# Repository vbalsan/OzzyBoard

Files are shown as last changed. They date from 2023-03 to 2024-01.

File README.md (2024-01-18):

# OzzyBoard
Allwinner V3s prototype SBC

Features : 
- Allwinner V3s SoC 1.2Ghz cortex-A with 64MB ram
- STM32F0, accessible through i2c and UART
- Interface for 0.91" OLED screen
- CH340N for serial through USB
- 40 pin screen interface for Adafruit 7"
- Audio with 3.5mm jack
- 8GB eMMC

Update 15/01/2024
Received the Rev B, changes are in the readme of its folder, main improvements are :
- Ethernet port right side
- Changed power supply of Serial to USB chip for the board own power, no accidental pull down now
- Heartbeat led added
- Added +5V port
- Added buttons
- EEPROM
- More leds...

Update 31/07/2023
- I realized that the LED I added for RX on UART0 is pulling the signal down if no USB with power is connected, resulting in getting stuck in uboot prompt at start, I will desolder it.
- forgot pull-up for I2C, so PMIC was impossible to talk to, fixed with internal pull-up in device tree.
- Tested LCD backlight, it works
- Tested LED on the back side with PWM, works fine too, I may use that with a kernel module to signal statuses. (uploaded a pic for it)
- Need to try transfering Uboot and Linux on eMMC

Update 05/05/2023
- Ethernet port LNK led is not working, mixed up connections, the eth connector has pin 9 as anode and 10 cathode, but on Kicad this was inverted.
- Board booting fine with kernel 6.1
- Made a custom device tree but with sunxi dtsi
- eMMC can be partitioned and formatted, perf test show +/- 40MB/s write or read
- Ethernet works, need to configure /etc/network/interfaces and add it to rootfs overlay though

Update 23/04/2023 :
- Ethernet port is inverted... 3D model on kicad was not accurate, lesson learned. Will replace with vertical models
- Green external led for LNK is too bright, Vf is equal to 2.7V for a forward current of 1mA and not typical 3V, so current in the end is more like 2mA
- Didn't test screen, need to update BSP with new device tree
- Power consumption is around 80mA, not bad

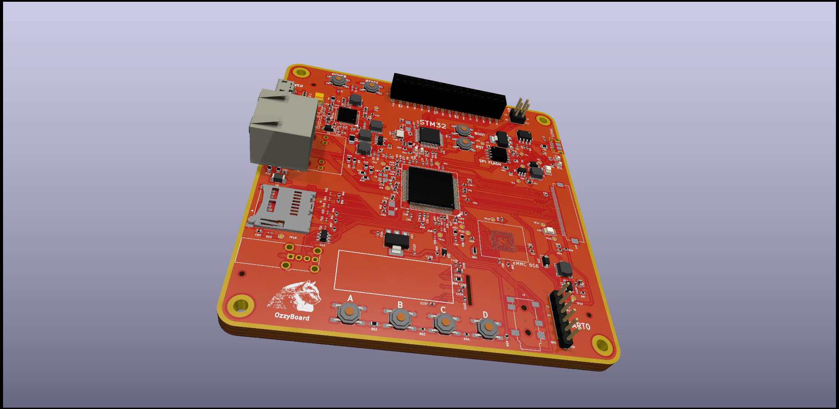
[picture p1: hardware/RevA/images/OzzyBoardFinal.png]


Board received : 
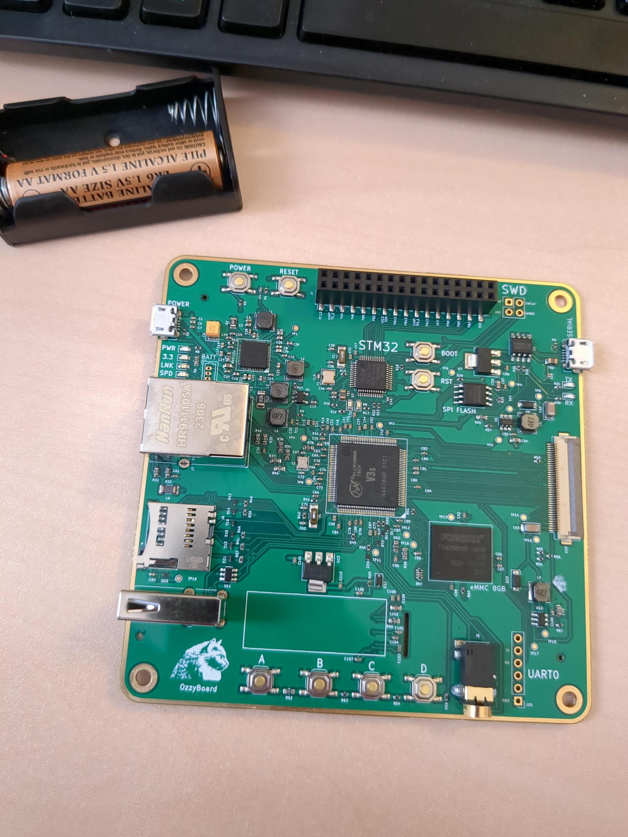
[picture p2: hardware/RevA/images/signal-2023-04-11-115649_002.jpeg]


Board with vital LEDs :
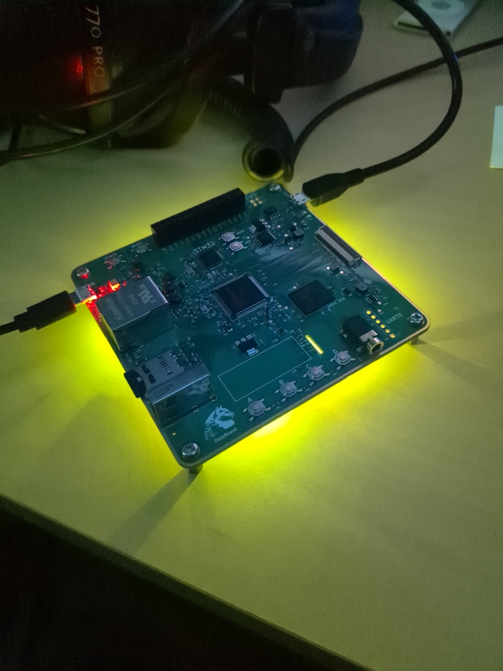
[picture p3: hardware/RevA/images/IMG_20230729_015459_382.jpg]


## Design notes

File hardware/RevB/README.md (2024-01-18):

# OzzyBoard
Allwinner V3s prototype SBC RevB

- Changed the Ethernet port , also this time it is right side
- Changed power supply of Serial to USB chip for the board own power, no accidental pull down now
- USB ports are more on board
- Heartbeat led added on PF6
- battery pins are bigger, JST model
- Added port for +5V
- UART serial port is now near serial usb
- Added func button
- Pull-up for i2c
- Added leds for CPU and Memory activity, through shift register

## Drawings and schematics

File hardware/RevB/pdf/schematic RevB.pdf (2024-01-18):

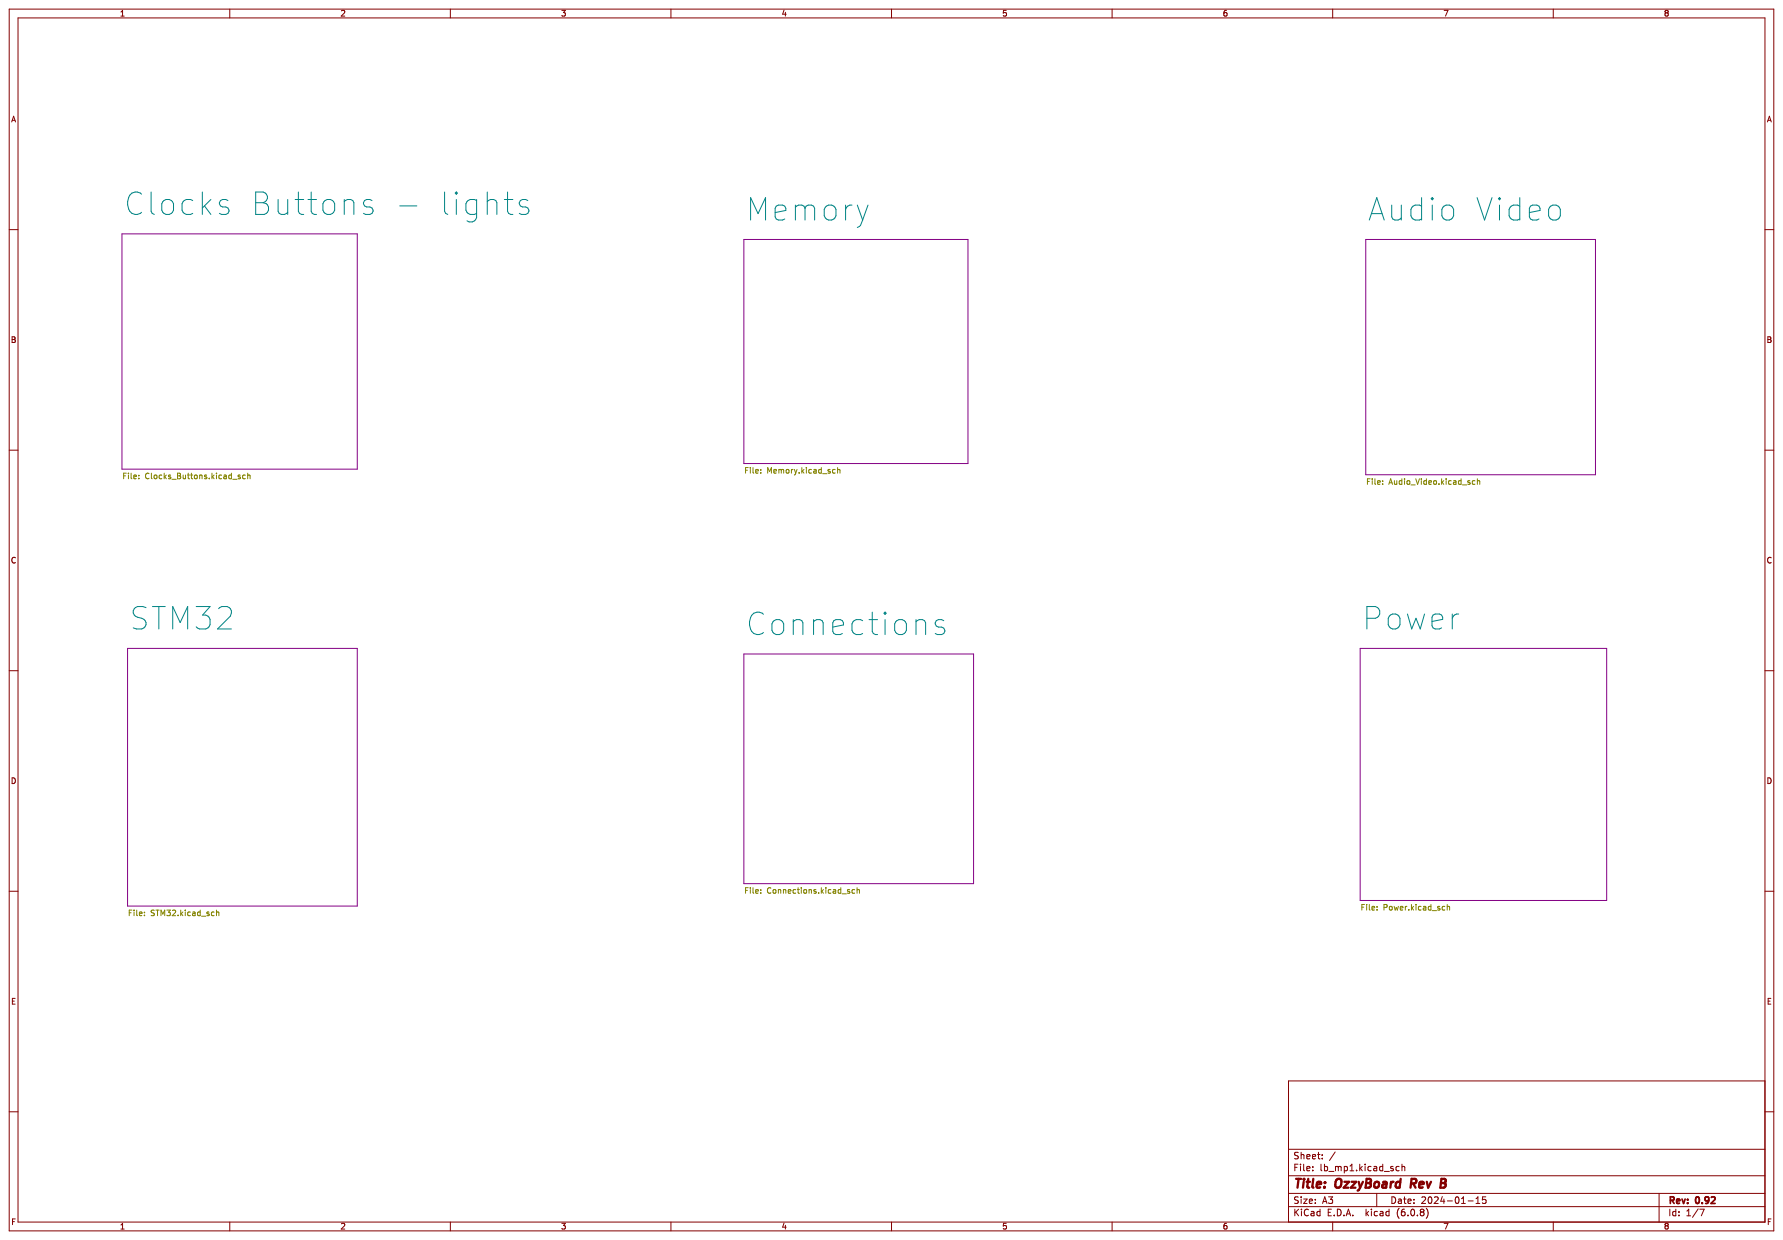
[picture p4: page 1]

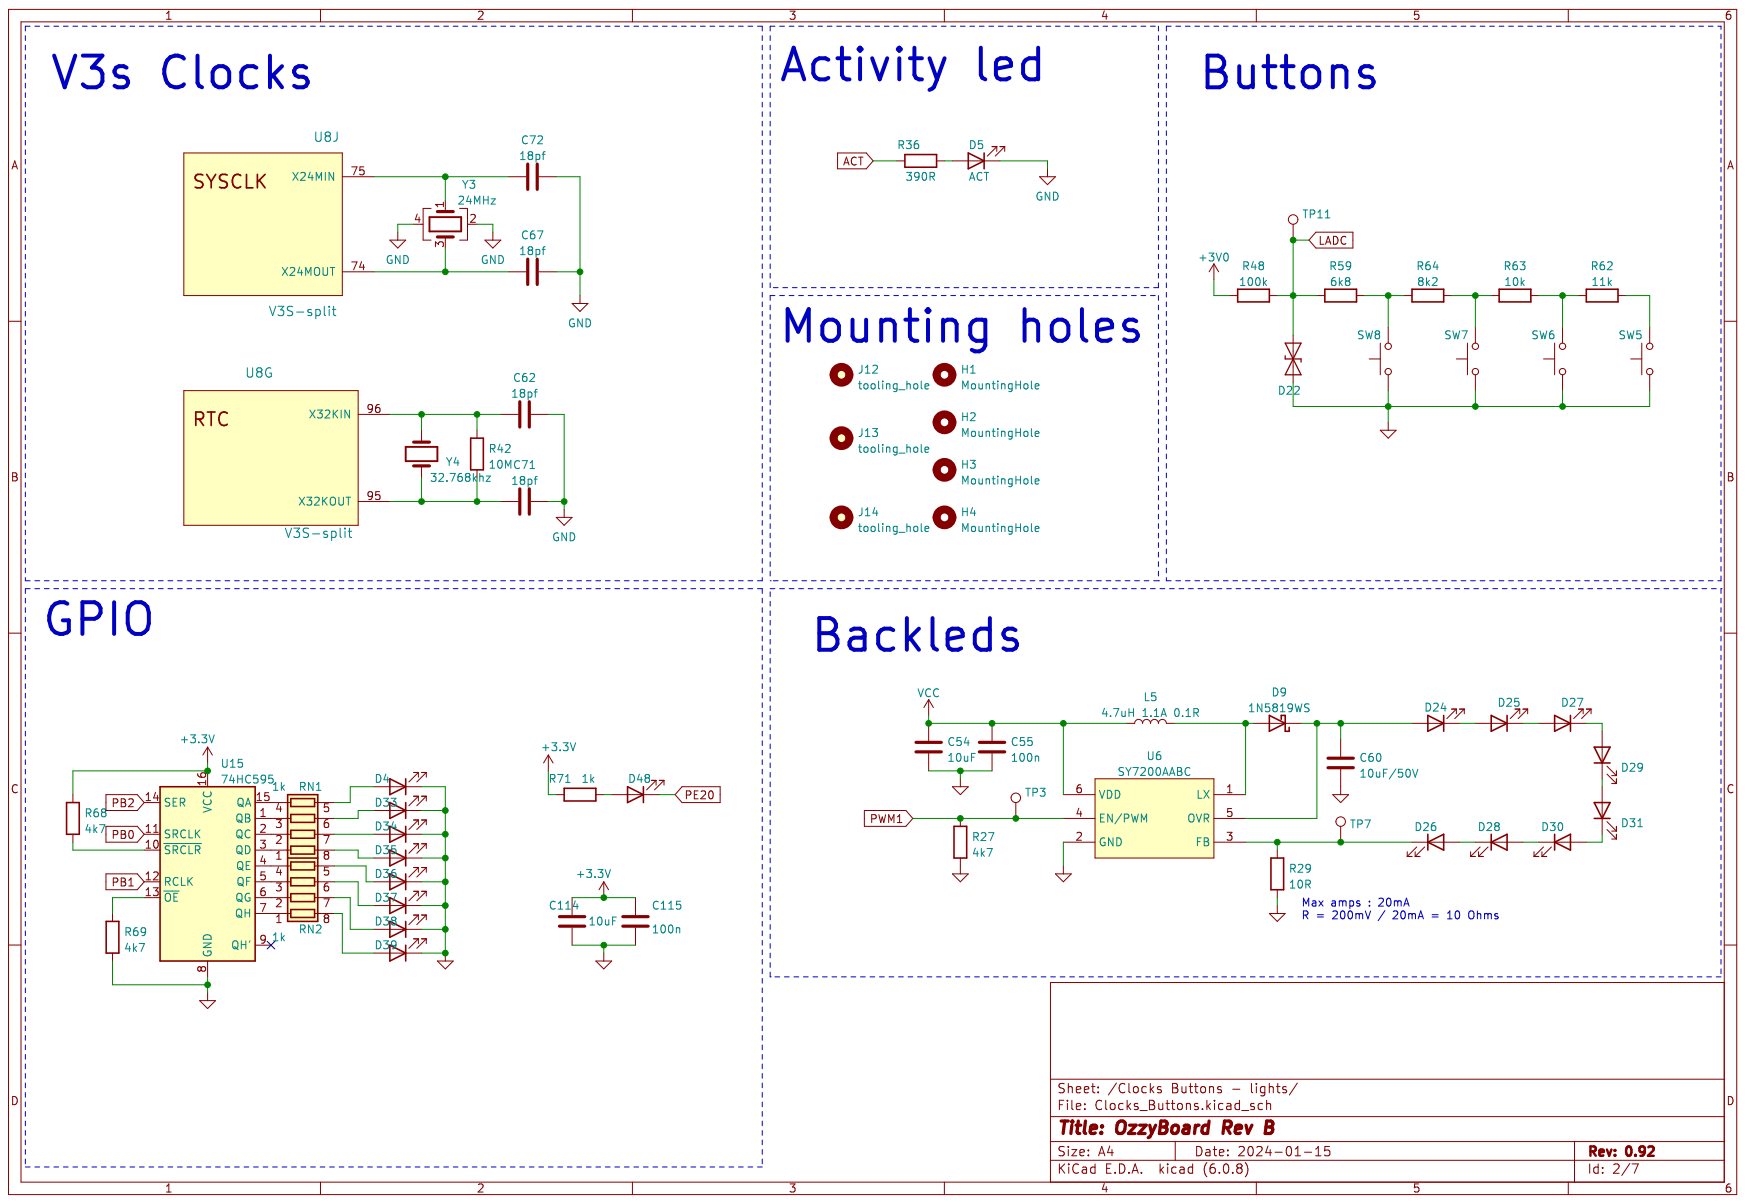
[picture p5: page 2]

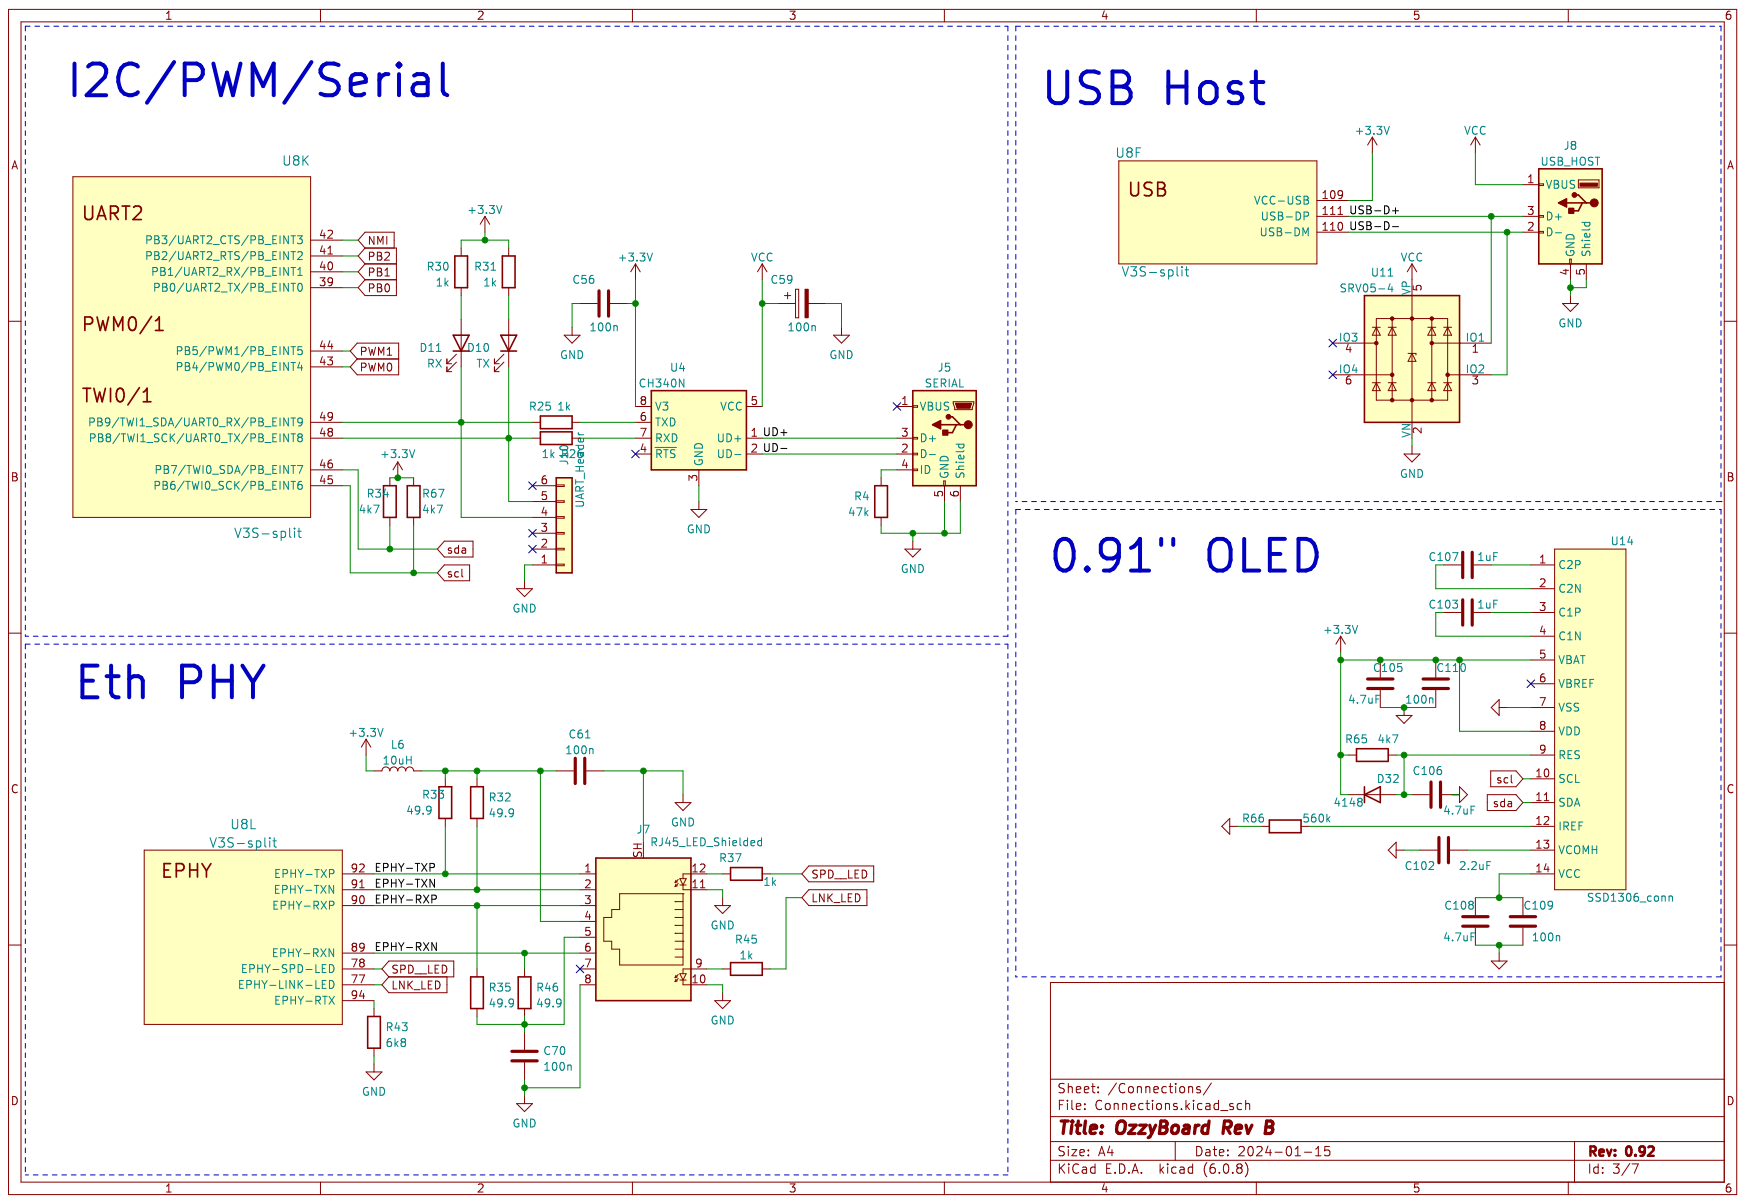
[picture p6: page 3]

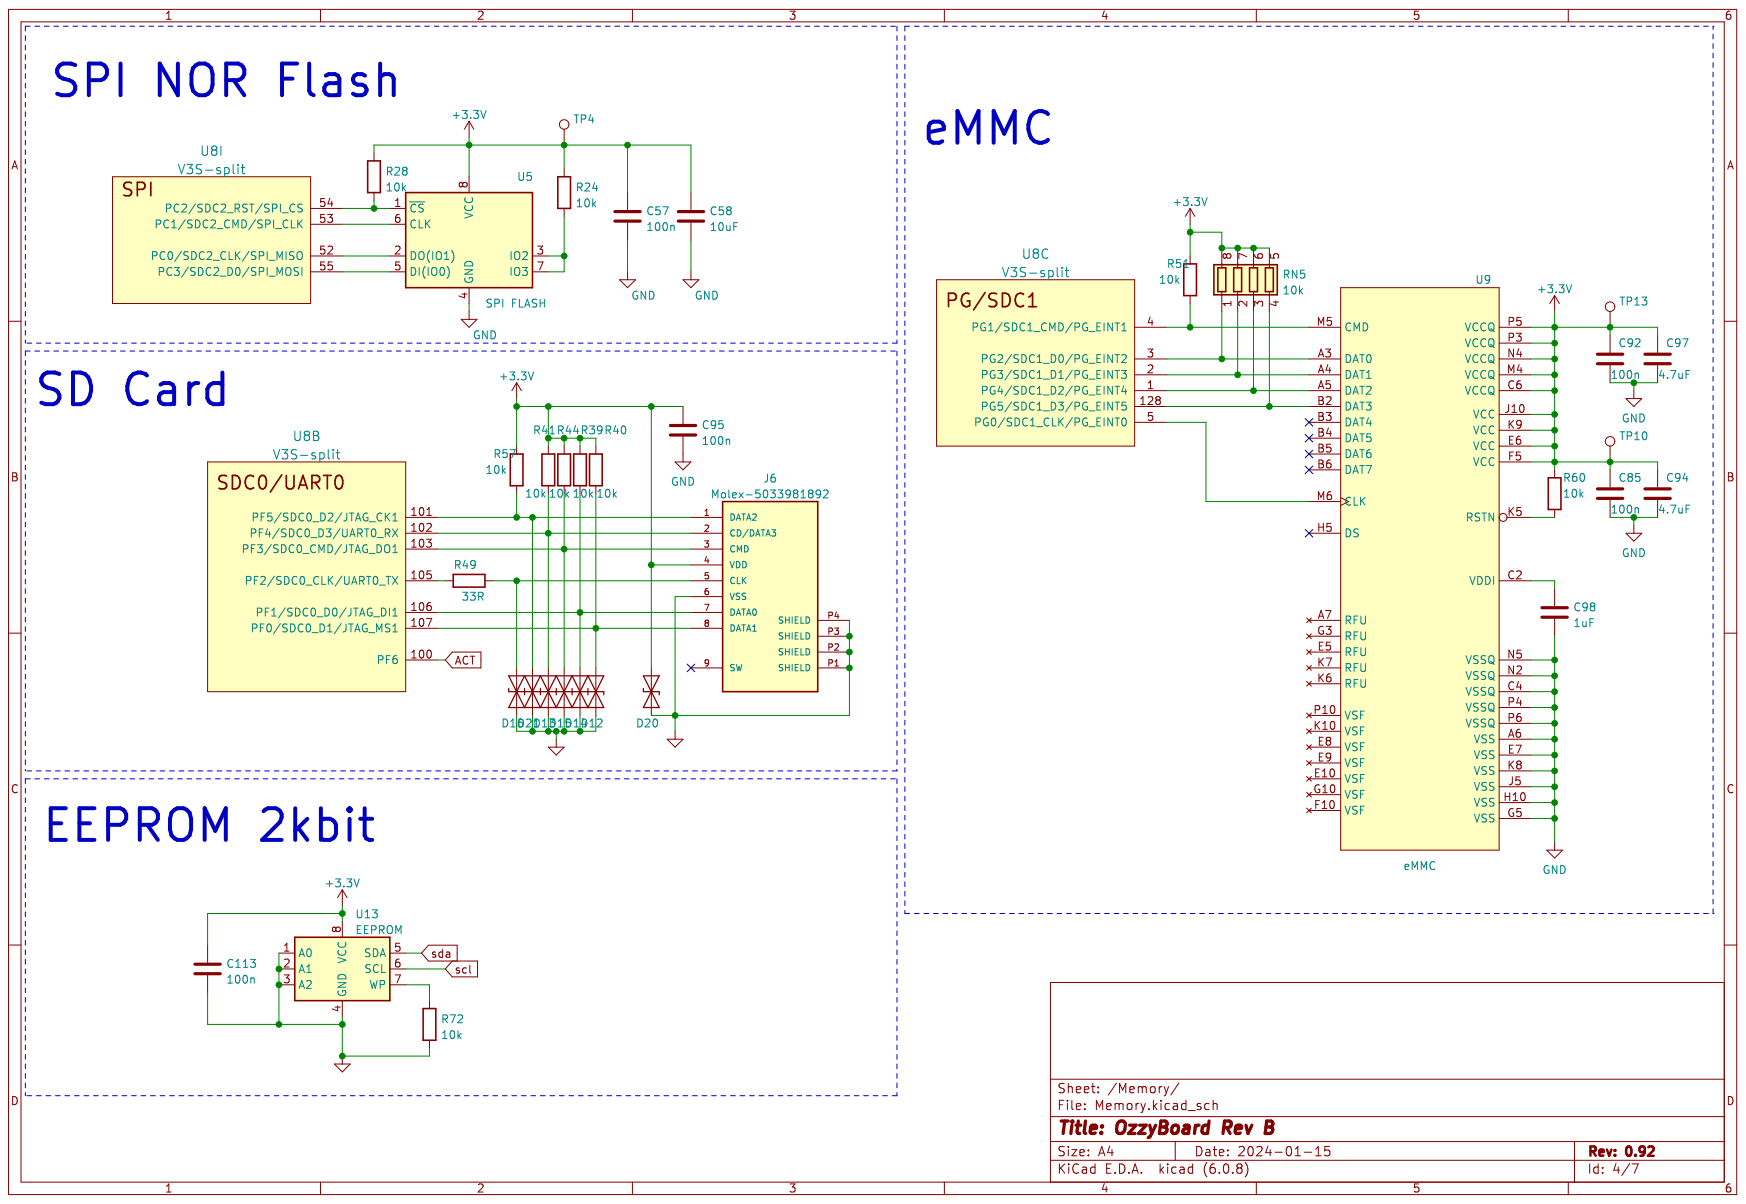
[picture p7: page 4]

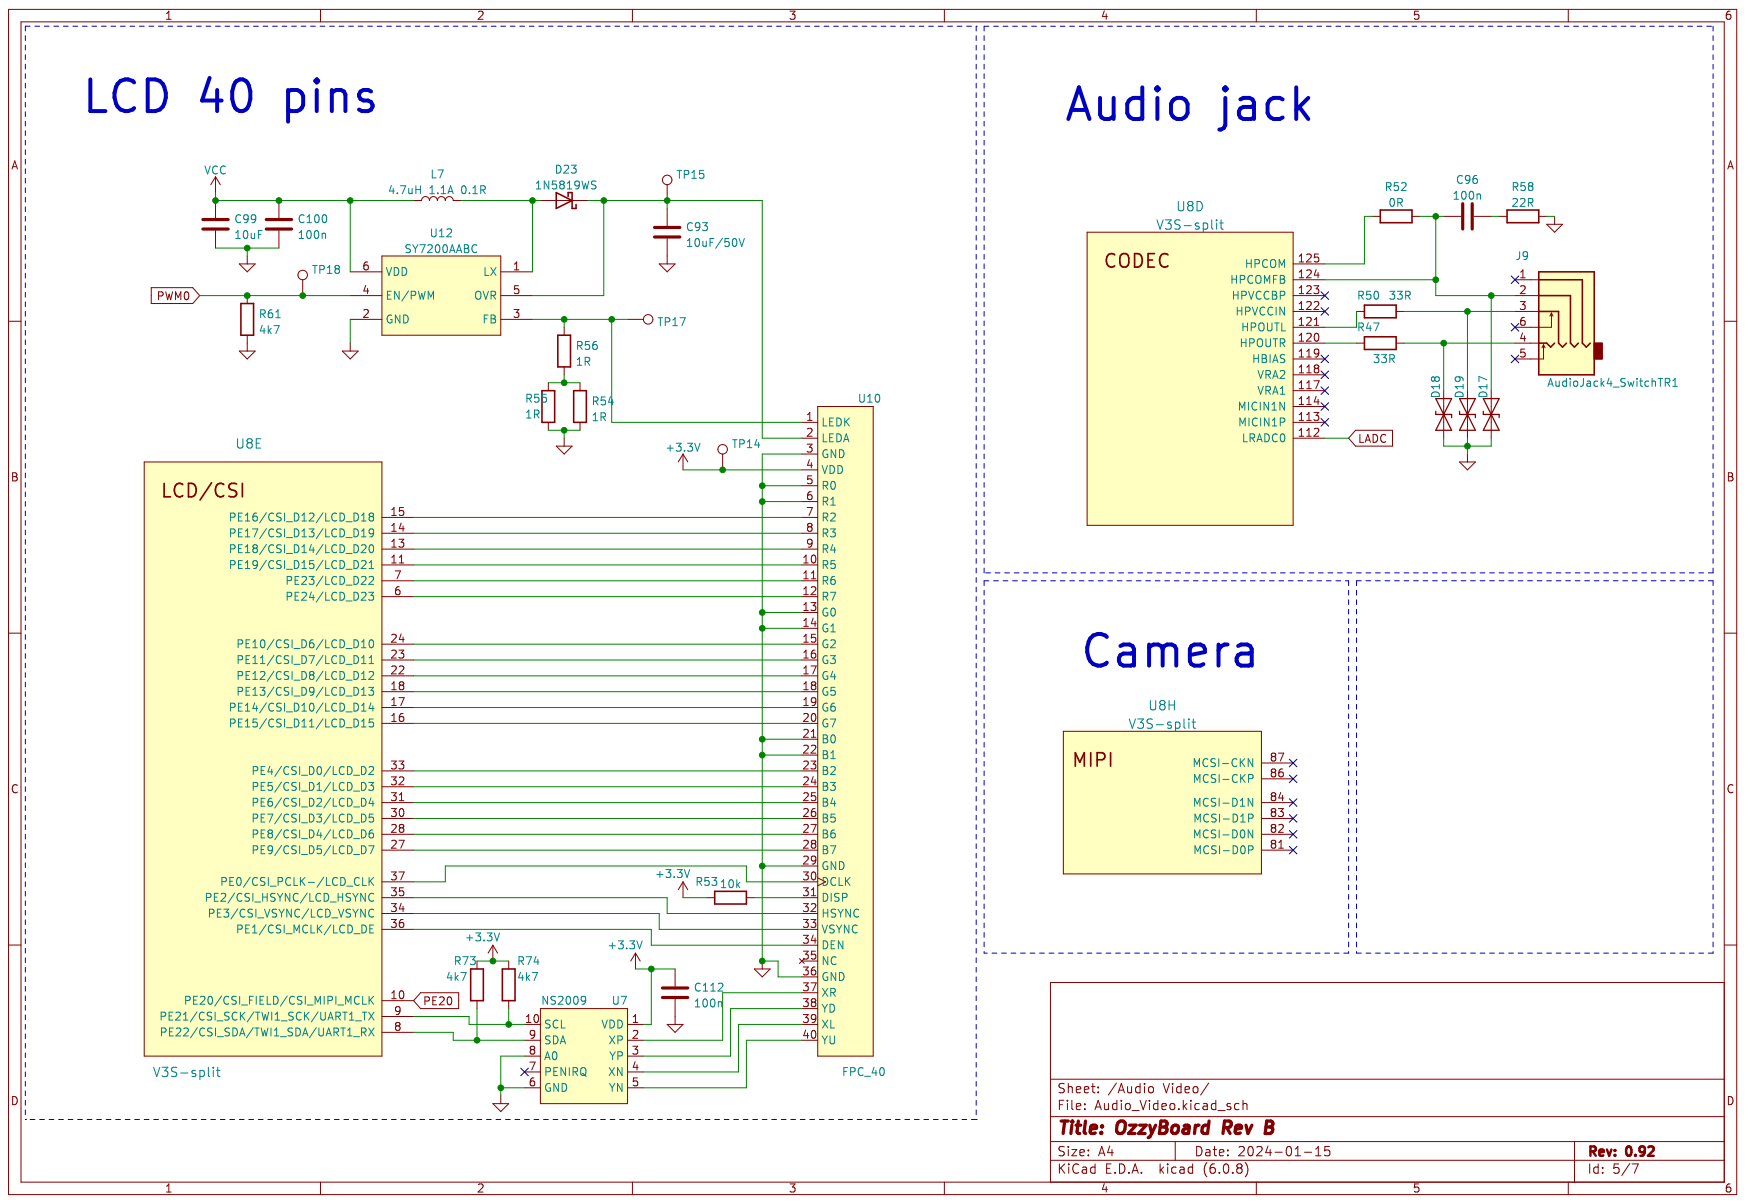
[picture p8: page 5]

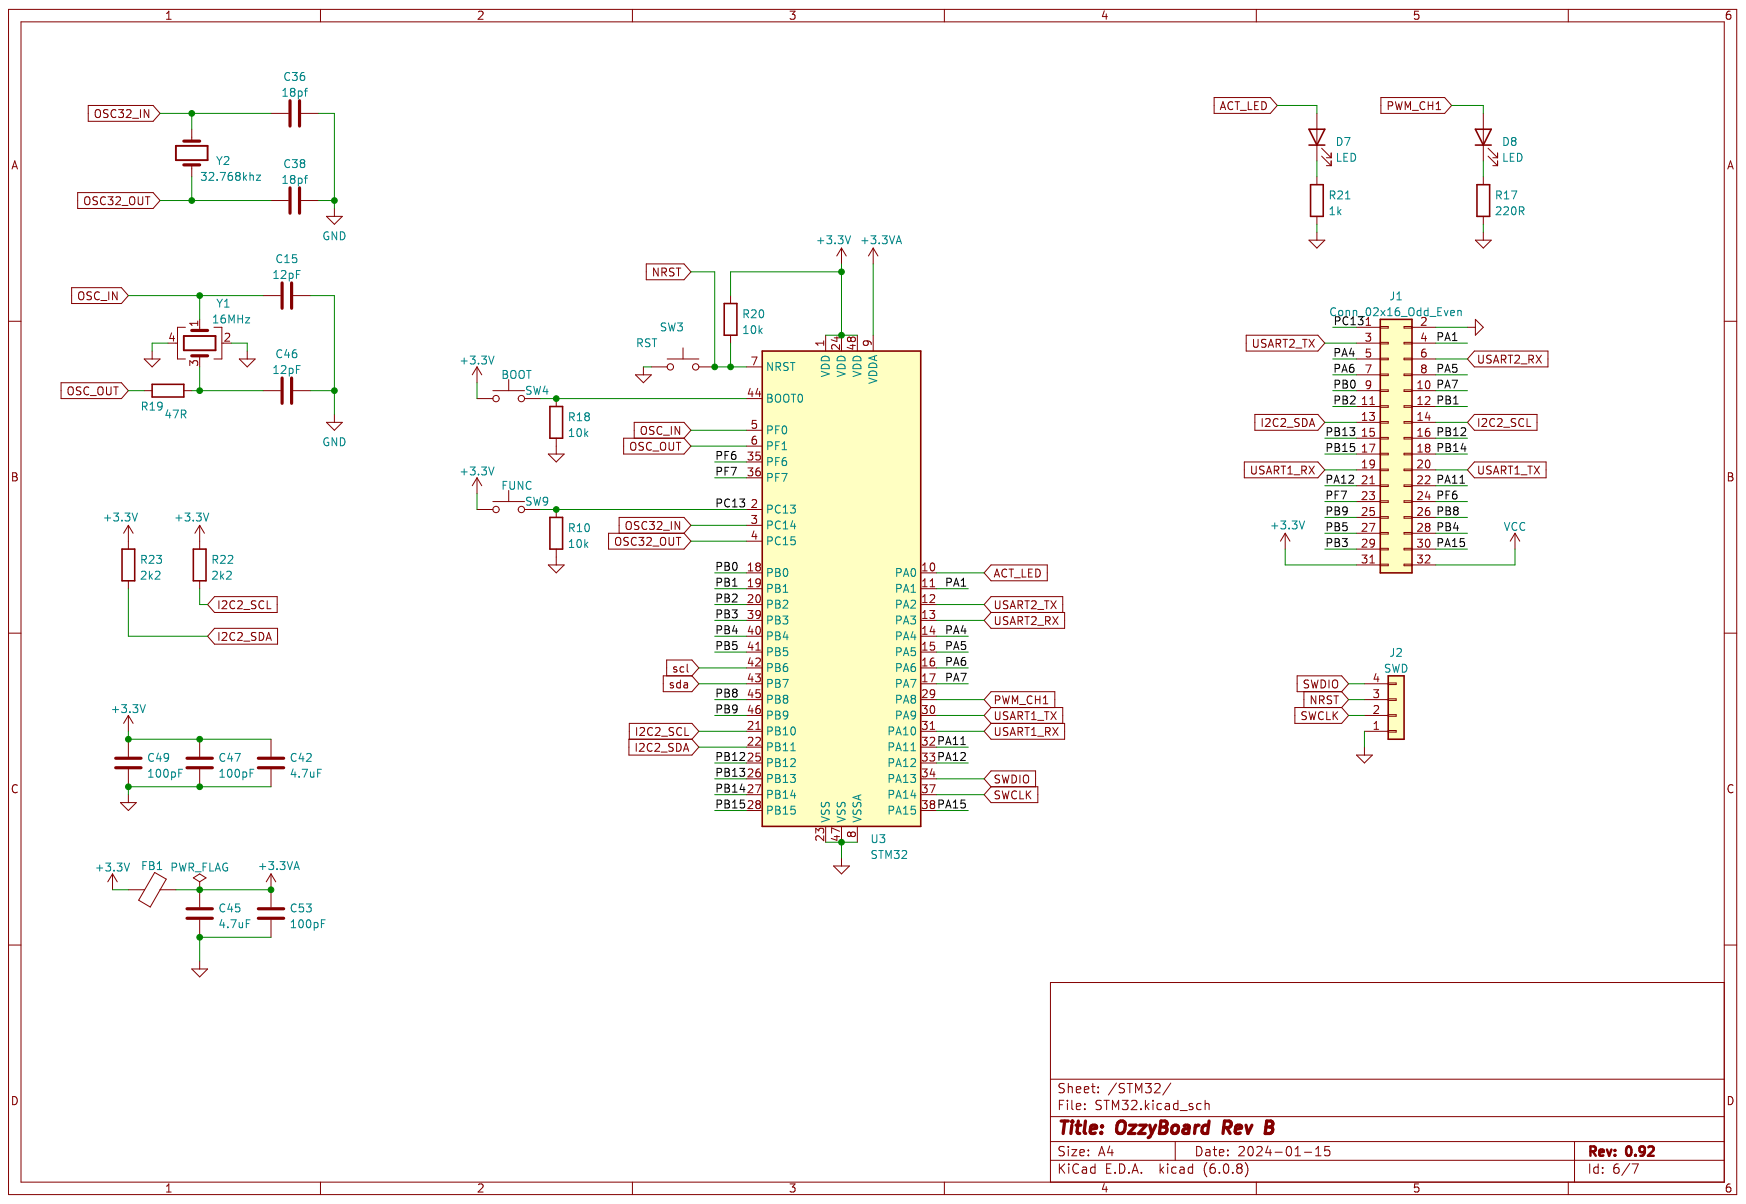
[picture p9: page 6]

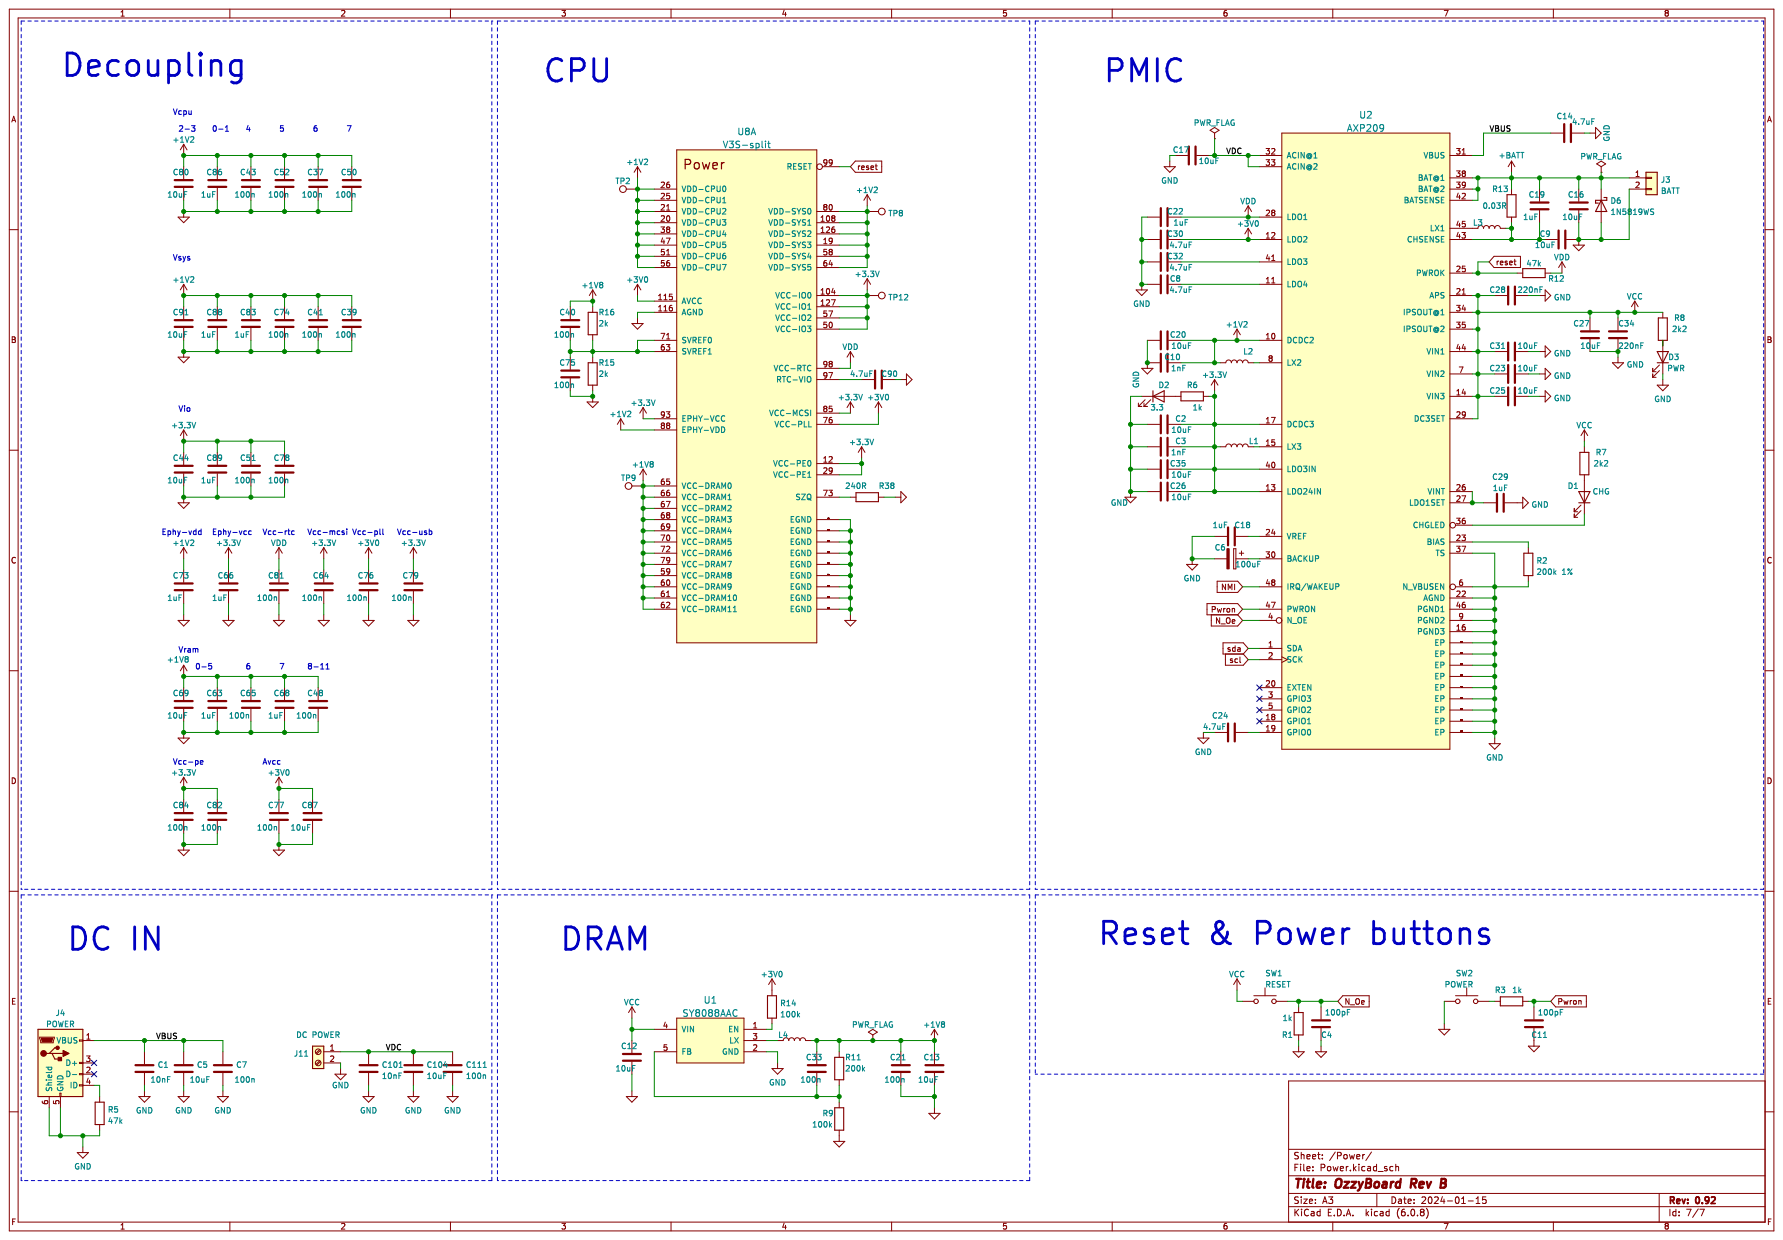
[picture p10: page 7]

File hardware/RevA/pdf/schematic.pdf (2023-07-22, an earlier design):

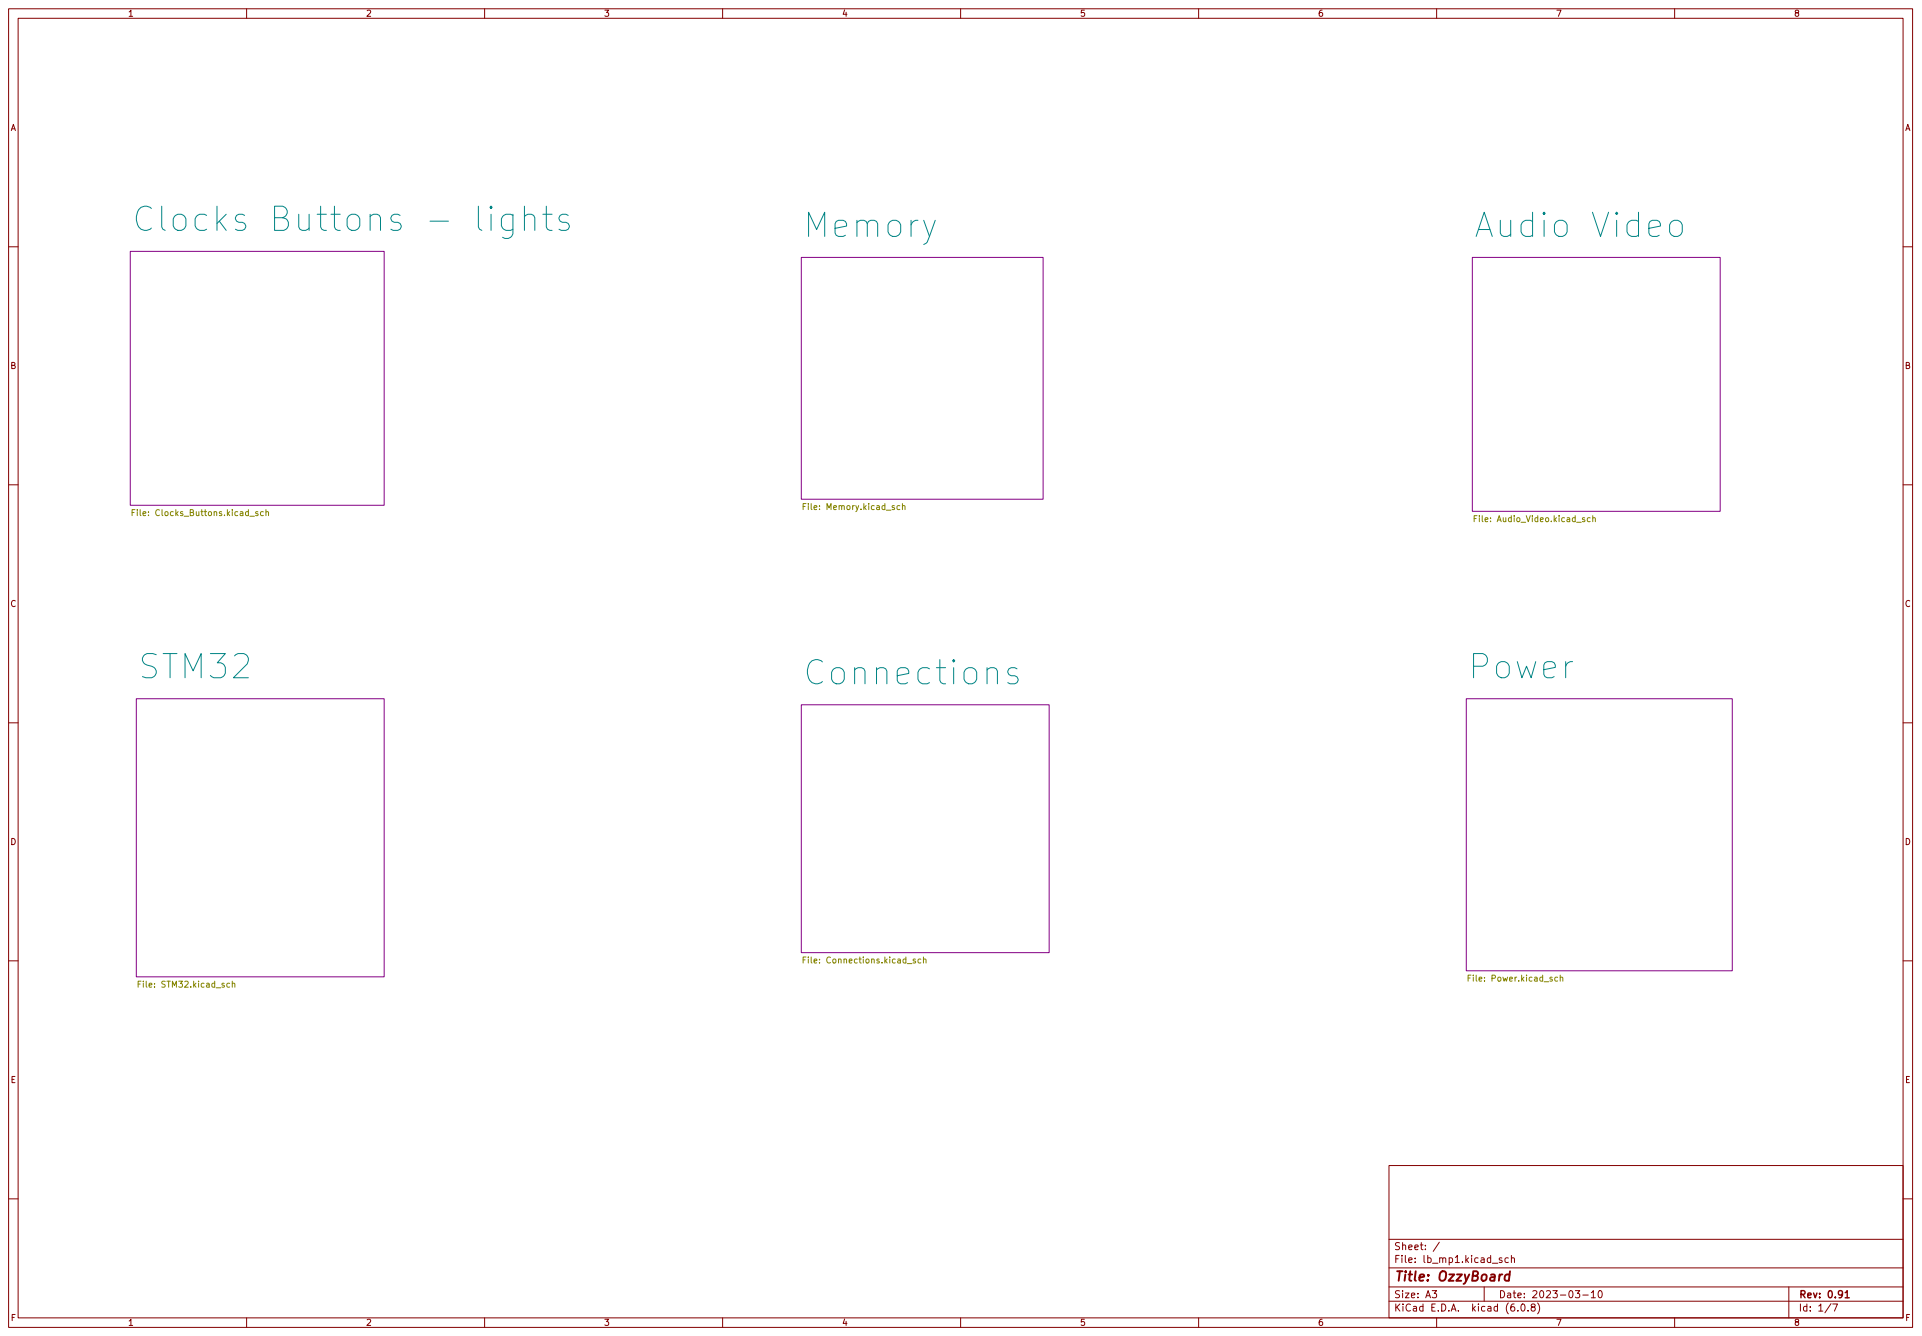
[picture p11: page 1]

File: STM32.kicad_sch Clocks Buttons - lights

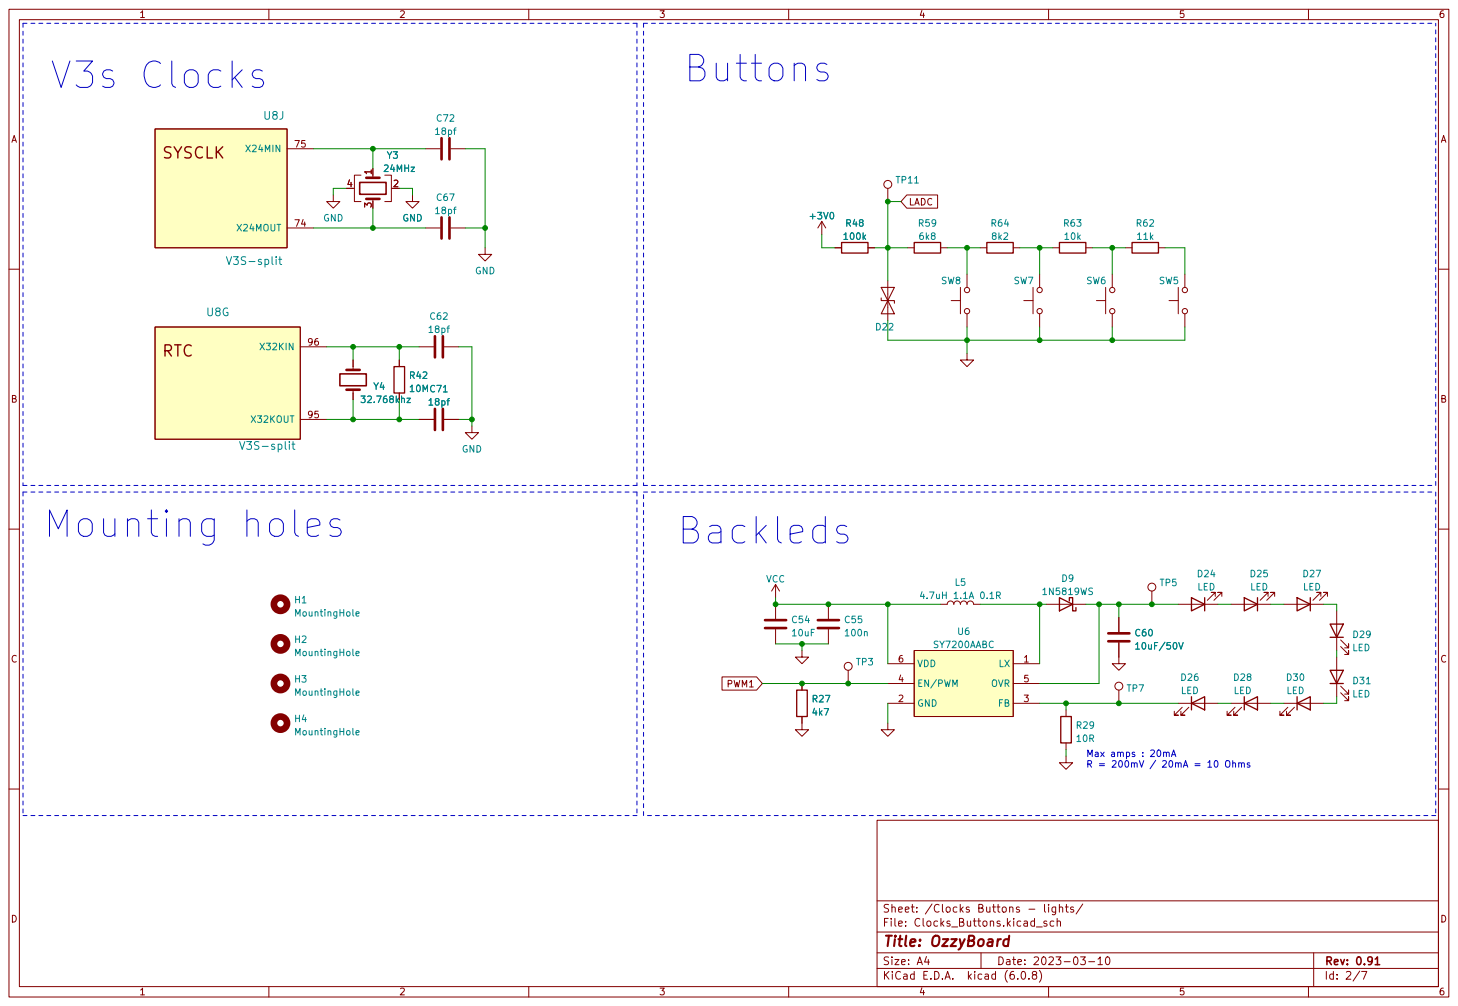
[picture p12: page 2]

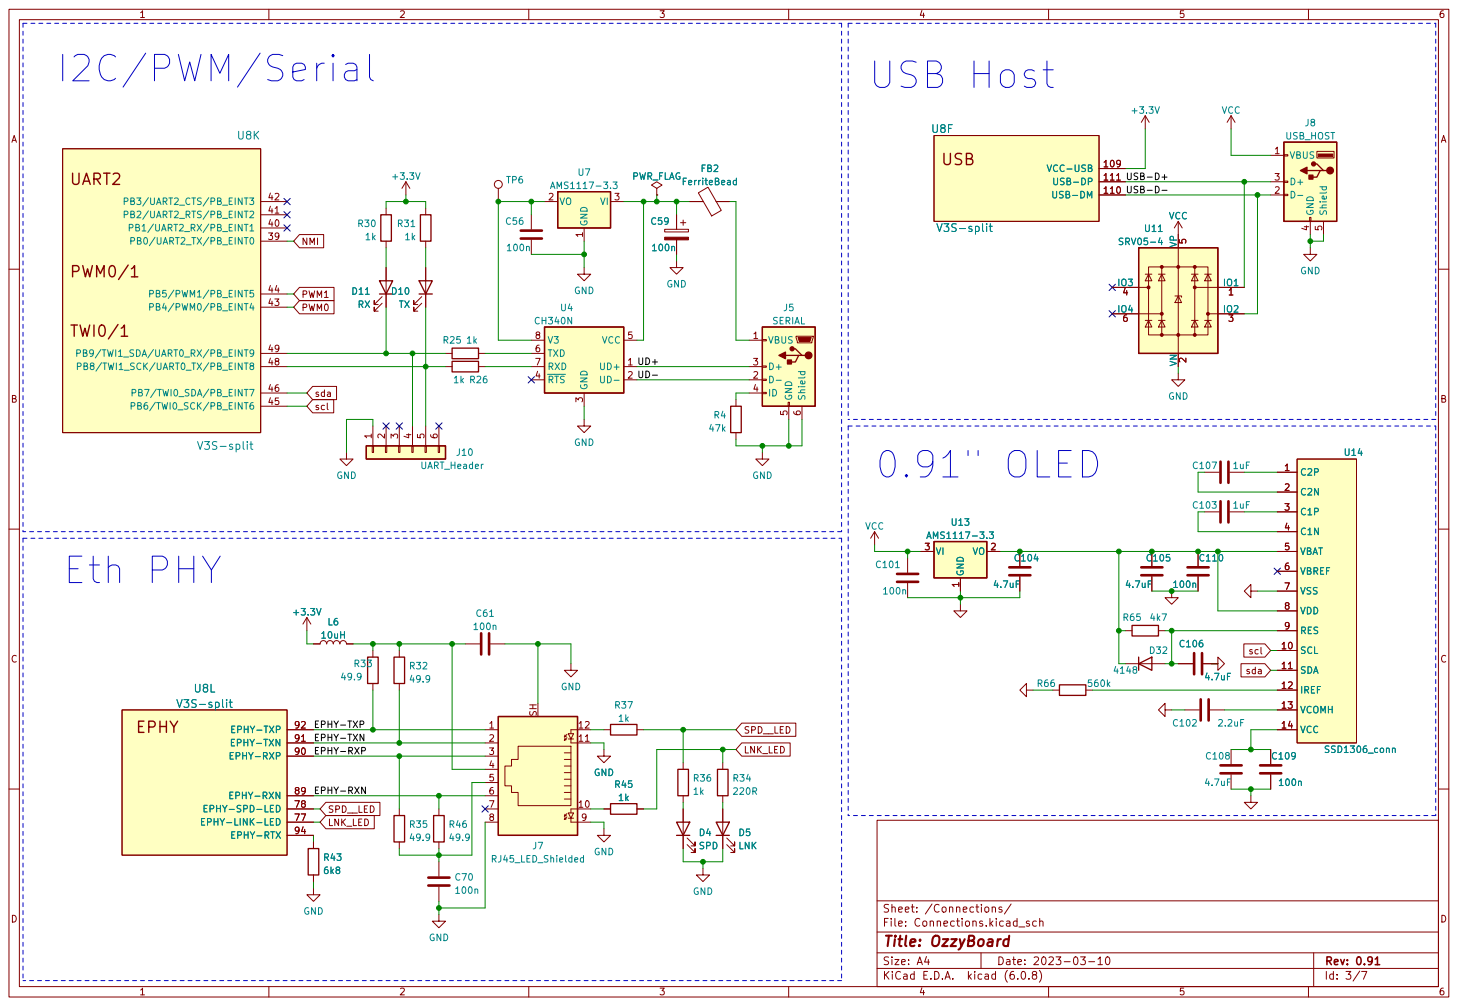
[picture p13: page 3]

3 ~{RTS} 4 VCC 5 TXD 6 RXD 7 V3 8 U4 CH340N

EPHY-RXP | 3

File: Connections.kicad_sch Sheet: /Connections/
Id: 3/7 Title: OzzyBoard

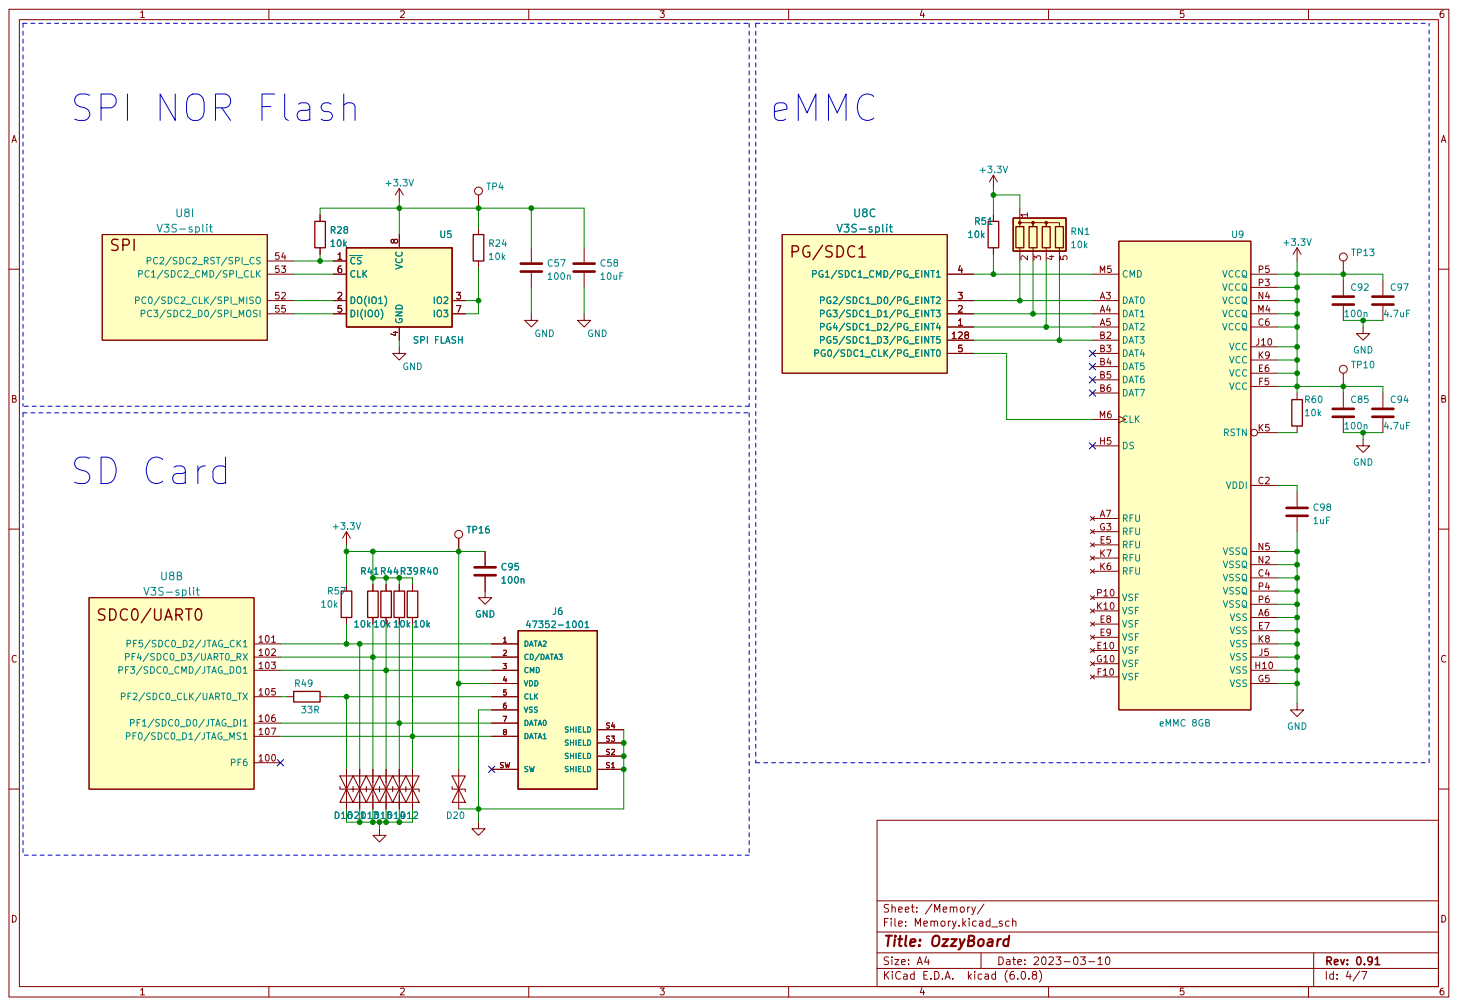
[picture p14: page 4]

8U5 SPI FLASH GND GND

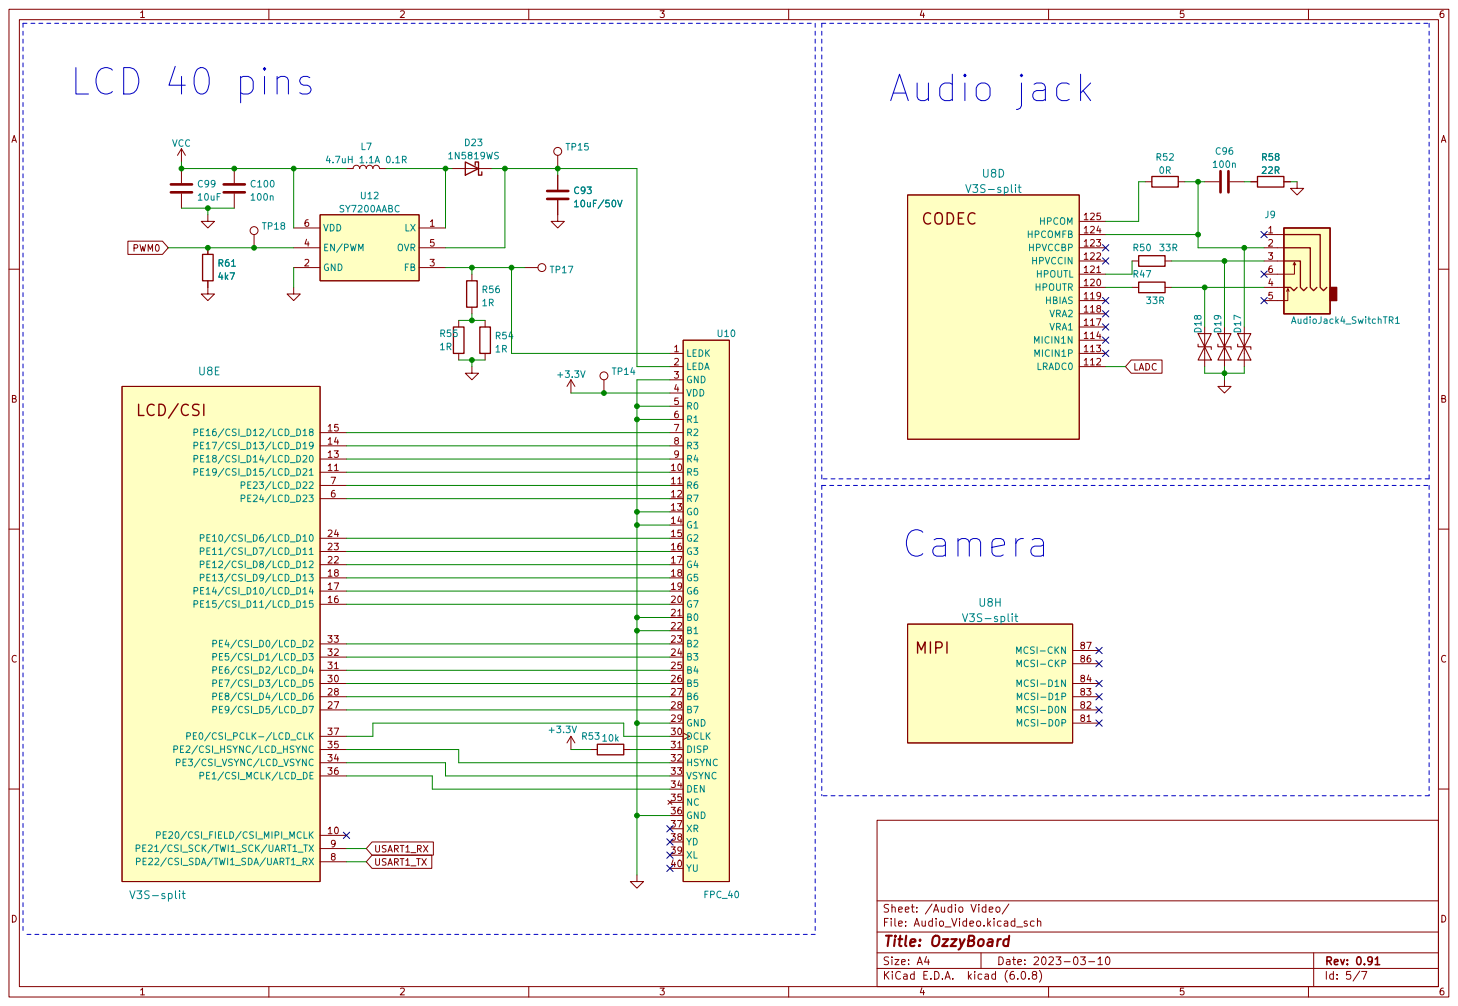
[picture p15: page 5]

File: Audio_Video.kicad_sch Sheet: /Audio Video/
Id: 5/7 Title: OzzyBoard


1 PA0 10 PA1 11 PA2 12 PA3 13 PA4 14 PA5 15 PA6 16 PA7 17 PB0 18 PB1 19 PC13 2 PB2 20 PB10 21 PB11 22 VSS 23 VDD 24 PB12 25 PB13 26 PB14 27 PB15 28 PA8 29 PC14 3 PA9 30 PA10 31 PA11 32 PA12 33 PA13 34 PF6 35 PF7 36 PA14 37 PA15 38 PB3 39 PC15 4 PB4 40 PB5 41 PB6 42 PB7 43 BOOT0 44 PB8 45 PB9 46 VSS 47 VDD 48 PF0 5 PF1 6 NRST 7 VSSA


File: Power.kicad_sch Sheet: /Power/
Id: 7/7 Title: OzzyBoard

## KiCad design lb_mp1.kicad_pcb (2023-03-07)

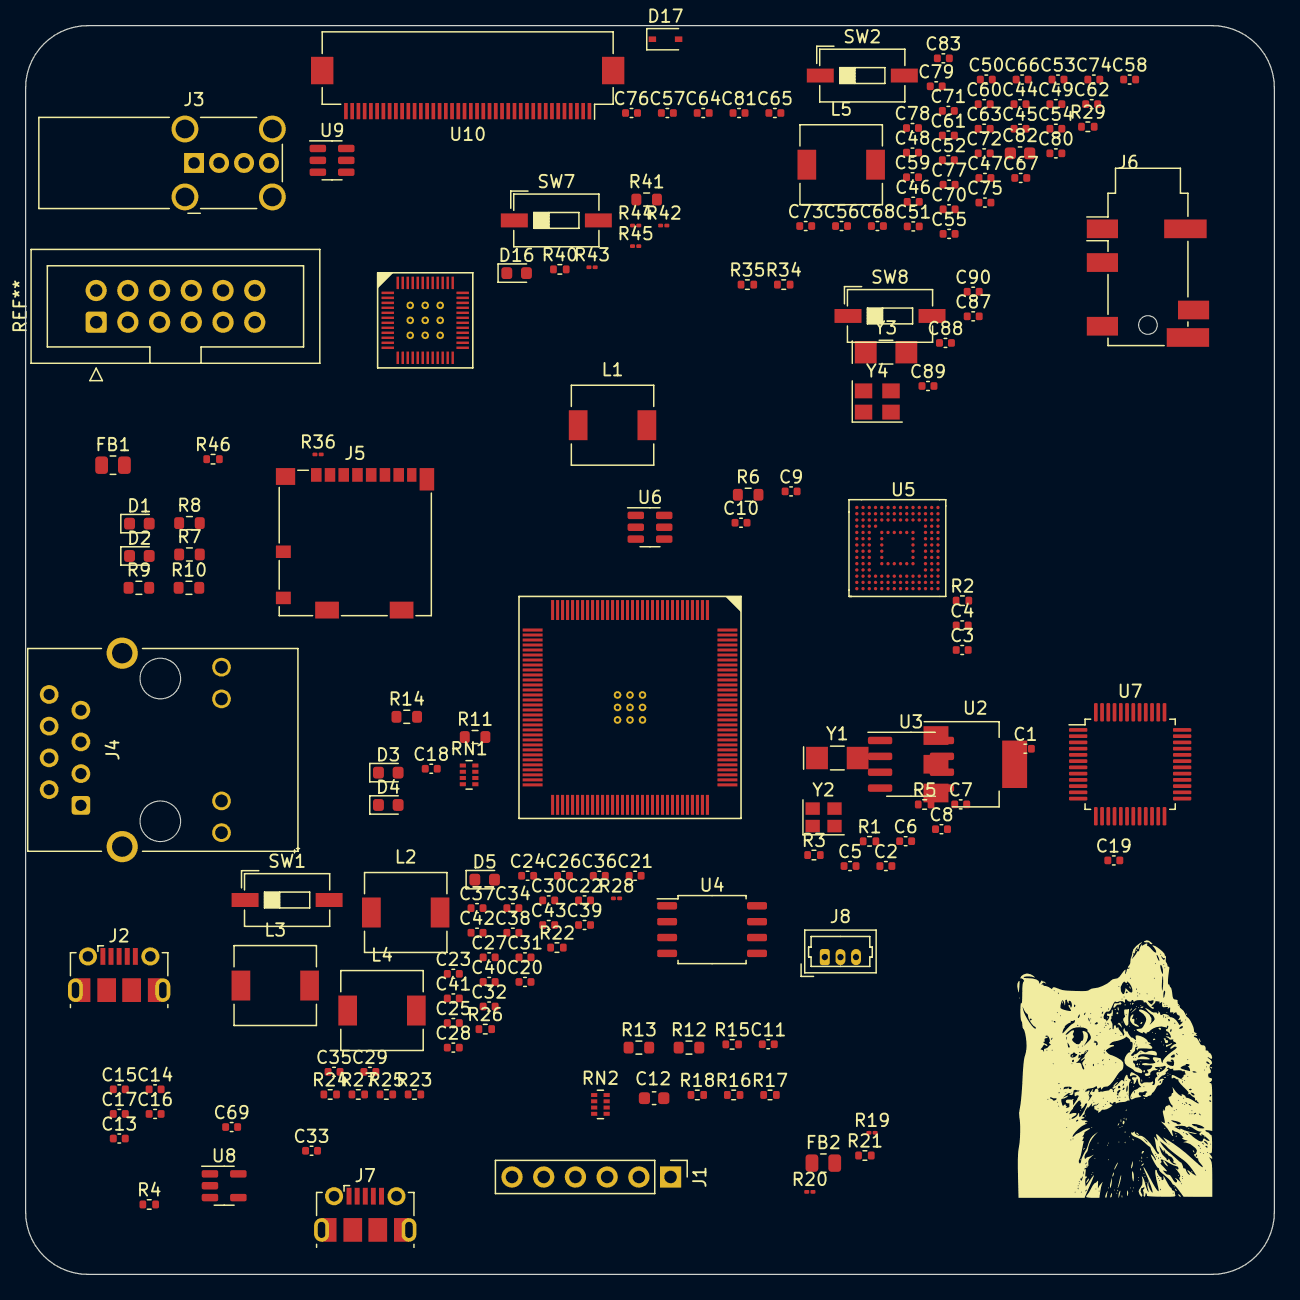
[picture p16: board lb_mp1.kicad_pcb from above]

Board: 2 copper layers, 100.0 x 100.0 mm, 169 parts (0 on the bottom side), 124 nets, no tracks yet.

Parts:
C1, C5, C6, C9, C10, C22, C27, C29, C31, C32, C34, C35, C36, C37, C38, C41, C42, C43, C44, C46, C47, C48, C49, C50, C51, C53, C55: 100n; C_0402_1005Metric
C2, C14, C15: 0.1uF; C_0402_1005Metric
C3, C4, C7, C8, C89, C90: 18pf; C_0402_1005Metric
C11, C18, C19, C21, C40, C45, C67: 10u; C_0402_1005Metric
C12: 100n; C_0603_1608Metric
C13: C; C_0402_1005Metric
C16, C17: 3.3uF; C_0402_1005Metric
C20, C23, C24, C25, C26, C28, C30, C39: 1u; C_0402_1005Metric
C33: 10n; C_0402_1005Metric
C52, C56, C61, C63, C65, C66, C74, C75, C76, C79, C81: 10uF; C_0402_1005Metric
C54, C58, C59, C60, C80: 4.7uF; C_0402_1005Metric
C57, C68, C72, C78: 1uF; C_0402_1005Metric
C62, C64: 1nF; C_0402_1005Metric
C69: 100uF; C_0402_1005Metric
C70: 4.7u; C_0402_1005Metric
C71, C77: 100pF; C_0402_1005Metric
C73, C83: 0.22uF; C_0402_1005Metric
C82: 10uF; C_0603_1608Metric
C87, C88: 12pf; C_0402_1005Metric
D1, D2, D3, D4, D5, D16: LED; LED_0603_1608Metric
D17: 1N5819WS; D_SOD-323
FB1, FB2: FerriteBead; R_0805_2012Metric
J1: UART_Header; PinHeader_1x06_P2.54mm_Vertical
J2: SERIAL; USB_Micro-B_Molex-105017-0001
J3: USB_HOST; USB_A_Wuerth_614004134726_Horizontal
J4: RJ45_LED_Shielded; RJ45_Hanrun_HR911105A
J5: Micro_SD_Card; microSD_HC_Molex_104031-0811
J6: AudioJack4_SwitchTR1; Jack_3.5mm_PJ31060-I_Horizontal
J7: USB_POWER; USB_Micro-B_Molex-105017-0001
J8: Bat; Molex_PicoBlade_53047-0310_1x03_P1.25mm_Vertical
L1: 10uH; L_6.3x6.3_H3
L2, L3, L4, L5: 4.7uH 1.1A 0.1R; L_6.3x6.3_H3
R1, R26, R40: 0R; R_0402_1005Metric
R2, R27: 22R; R_0402_1005Metric
R3, R21, R29: 47k; R_0402_1005Metric
R4: 0.5; R_0402_1005Metric
R5: 10M; R_0402_1005Metric
R6: 6k; R_0603_1608Metric
R7, R8, R9, R10: 49.9; R_0603_1608Metric
R11: 1K; R_0603_1608Metric
R12, R13, R14: 1k; R_0603_1608Metric
R15, R16, R17, R18, R23, R46: 10k; R_0402_1005Metric
R19, R20: 470; R_01005_0402Metric
R22, R24, R25, R34, R35: 33R; R_0402_1005Metric
R28, R45: 10k; R_01005_0402Metric
R36, R42: 1k; R_01005_0402Metric
R41: 0.03R; R_0603_1608Metric
R43: 200k 1%; R_01005_0402Metric
R44: 47k; R_01005_0402Metric
RN1, RN2: 10k; R_Array_Concave_4x0402
SW1, SW2, SW7, SW8: SW_SPDT; SW_DIP_SPSTx01_Slide_6.7x4.1mm_W6.73mm_P2.54mm_LowProfile_J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
U1: V3S-split; V3s-ELQFP-128
U2: AMS1117-3.3; SOT-223-3_TabPin2
U3: CH340N; SOIC-8_3.9x4.9mm_P1.27mm
U4: W25Q128JVS; SOIC-8_5.23x5.23mm_P1.27mm
U5: FEMDRM008G-58A39_NO_NC; EMMC_JLCP
U6: SRV05-4; SOT-23-6
U7: STM32F030C8Tx; LQFP-48_7x7mm_P0.5mm
U8: SY8088AAC; SOT-23-5
U9: SY7200AABC; SOT-23-6
U10: FPC_40; Hirose_FH12-40S-0.5SH_1x40-1MP_P0.50mm_Horizontal
U11: AXP209; AXP209-QFN48
Y1, Y3: 32.768khz; Crystal_SMD_MicroCrystal_CC7V-T1A-2Pin_3.2x1.5mm_HandSolder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
Y2: 24MHz; Crystal_SMD_2520-4Pin_2.5x2.0mm
Y4: 16MHz; Crystal_SMD_3225-4Pin_3.2x2.5mm

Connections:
+1V2: C11.1, C18.1, C20.1, C23.1, C24.1, C29.1, C30.1, C36.1, C37.1, C41.1, C42.1, C46.1, C47.1, C61.1, C62.1, L3.1, U1.19 (VDD-SYS3), U1.20 (VDD-CPU3), U1.21 (VDD-CPU2), U1.25 (VDD-CPU1), U1.26 (VDD-CPU0), U1.38 (VDD-CPU4), U1.47 (VDD-CPU5), U1.51 (VDD-CPU6), U1.56 (VDD-CPU7), U1.58 (VDD-SYS4), U1.64 (VDD-SYS5), U1.80 (VDD-SYS0), U1.88 (EPHY-VDD), U1.108 (VDD-SYS1), U1.126 (VDD-SYS2), U11.10 (DCDC2)
+1V8: C21.1, C26.1, C32.1, C39.1, C43.1, C50.1, C53.1, C55.1, C56.1, L2.2, U1.59 (VCC-DRAM8), U1.60 (VCC-DRAM9), U1.61 (VCC-DRAM10), U1.62 (VCC-DRAM11), U1.65 (VCC-DRAM0), U1.66 (VCC-DRAM1), U1.67 (VCC-DRAM2), U1.68 (VCC-DRAM3), U1.69 (VCC-DRAM4), U1.70 (VCC-DRAM5), U1.72 (VCC-DRAM6), U1.79 (VCC-DRAM7)
+3.3V: C5.1, C12.1, C14.1, C15.1, C16.1, C17.1, C19.1, C22.1, C25.1, C27.1, C28.1, C31.1, C38.1, C44.1, C63.1, C64.1, C65.1, C66.1, FB2.2, J5.4 (VDD), L1.1, L4.1, R15.1, R16.1, R17.1, R18.1, R19.1, R20.1, R23.1, R46.1, RN1.1 (common), RN2.1 (common), SW8.1 (A), U1.12 (VCC-PE0), U1.29 (VCC-PE1), U1.50 (VCC-IO3), U1.57 (VCC-IO2), U1.85 (VCC-MCSI), U1.93 (EPHY-VCC), U1.104 (VCC-IO0), U1.127 (VCC-IO1), U4.8 (VCC), U5.C6 (VCCQ), U5.E6 (VCC), U5.F5 (VCC), U5.J10 (VCC), U5.K9 (VCC), U5.M4 (VCCQ), U5.N4 (VCCQ), U5.P3 (VCCQ), U5.P5 (VCCQ), U7.1 (VDD), U7.24 (VDD), U7.48 (VDD), U10.4 (VDD), U11.13 (LDO24IN), U11.17 (DCDC3), U11.40 (LDO3IN)
+3V0: C35.1, C40.1, C48.1, C58.2, U1.76 (VCC-PLL), U1.115 (AVCC), U11.12 (LDO2)
+BATT: C78.1, C81.1, J8.1, R41.2, U11.38 (BAT@1), U11.39 (BAT@2), U11.42 (BATSENSE)
+VDC: C33.1, C45.1, C49.1, C67.2, J7.1 (VBUS), U11.32 (ACIN@1), U11.33 (ACIN@2)
GND: C1.2, C2.2, C3.2, C4.2, C5.2, C7.2, C8.2, C9.2, C10.2, C11.2, C12.2, C13.2, C14.2, C15.2, C16.2, C17.2, C18.2, C19.2, C20.2, C21.2, C22.2, C23.2, C24.2, C25.2, C26.2, C27.2, C28.2, C29.2, C30.2, C31.2, C32.2, C33.2, C34.2, C35.2, C36.2, C37.2, C38.2, C39.2, C40.2, C41.2, C42.2, C43.2, C44.2, C45.2, C46.2, C47.2, C48.2, C49.2, C51.2, C52.2, C54.1, C55.2, C56.2, C57.1, C58.1, C59.1, C60.2, C61.2, C62.2, C63.2, C64.2, C65.2, C66.2, C67.1, C68.1, C69.1, C70.1, C71.1, C72.2, C73.2, C74.2, C75.2, C76.2, C77.1, C79.2, C80.2, C81.2, C82.2, C83.2, C87.2, C88.2, C89.2, C90.2, D1.1 (K), D2.1 (K), J1.1, J2.5 (GND), J2.6 (Shield), J3.4 (GND), J3.5 (Shield), J4.8, J4.9, J4.11, J4.SH, J5.6 (VSS), J5.9 (SHIELD), J7.5 (GND), J7.6 (Shield), J8.2, R2.1, R3.2, R6.2, R21.2, R27.1, R29.2, R36.1, R43.1, SW1.2 (B), SW2.2 (B), SW7.2 (B), U1.116 (AGND), U1.GND$1 (EGND), U1.GND$2 (EGND), U1.GND$3 (EGND), U1.GND$4 (EGND), U1.GND$5 (EGND), U1.GND$6 (EGND), U1.GND$7 (EGND), U1.GND$8 (EGND), U1.GND$9 (EGND), U2.1 (GND), U3.3 (GND), U4.4 (GND), U5.A6 (VSS), U5.C4 (VSSQ), U5.E7 (VSS), U5.G5 (VSS), U5.H10 (VSS), U5.J5 (VSS), U5.K8 (VSS), U5.N2 (VSSQ), U5.N5 (VSSQ), U5.P4 (VSSQ), U5.P6 (VSSQ), U6.2 (VN), U7.8 (VSSA), U7.23 (VSS), U7.47 (VSS), U8.2 (GND), U9.2 (GND), U10.3 (GND), U10.5 (R0), U10.6 (R1), U10.13 (G0), U10.14 (G1), U10.21 (B0), U10.22 (B1), U10.29 (GND), U10.36 (GND), U11.6 (N_VBUSEN), U11.9 (PGND2), U11.16 (PGND3), U11.22 (AGND), U11.37 (TS), U11.46 (PGND1), U11.GND$1 (EP), U11.GND$2 (EP), U11.GND$3 (EP), U11.GND$4 (EP), U11.GND$5 (EP), U11.GND$6 (EP), U11.GND$7 (EP), U11.GND$8 (EP), U11.GND$9 (EP), Y2.2, Y2.4, Y4.2, Y4.4
LNK_LED: R12.2, R14.2, U1.77 (EPHY-LINK-LED)
NMI: U1.39 (PB0/UART2_TX/PB_EINT0), U11.48 (IRQ/WAKEUP)
N_Oe: C71.2, R36.2, U11.4 (N_OE)
unnamed: C1.1, R2.2, U2.2 (VO), U3.8 (V3)
unnamed: C2.1, FB1.2, U2.3 (VI), U3.5 (VCC)
unnamed: C3.1, R5.1, U1.96 (X32KIN), Y1.2
unnamed: C4.1, R5.2, U1.95 (X32KOUT), Y1.1
unnamed: C6.1, R27.2
unnamed: C6.2, J6.R2, R26.1, U1.124 (HPCOMFB)
unnamed: C7.1, U1.75 (X24MIN), Y2.1
unnamed: C8.1, U1.74 (X24MOUT), Y2.3
unnamed: C9.1, J4.5, R9.2, R10.2
unnamed: C10.1, J4.4, L1.2, R7.1, R8.1
unnamed: C13.1, U5.C2 (VDDI)
unnamed: C50.2, C51.1, U1.63 (SVREF1), U1.71 (SVREF0)
unnamed: C53.2, U8.5 (FB)
unnamed: C54.2, U1.97 (RTC-VIO)
unnamed: C59.2, U11.41 (LDO3)
unnamed: C60.1, U11.11 (LDO4)
unnamed: C68.2, U11.24 (VREF)
unnamed: C69.2, U11.30 (BACKUP)
unnamed: C70.2, U11.19 (GPIO0)
unnamed: C72.1, U11.26 (VINT), U11.27 (LDO1SET)
unnamed: C78.2, C79.1, L5.2, R41.1, U11.43 (CHSENSE)
unnamed: C80.1, R40.2, U11.31 (VBUS)
unnamed: D17.1 (K), U9.5 (OVR), U10.2 (LEDA)
unnamed: C88.1, Y4.3
unnamed: D1.2 (A), R13.1
unnamed: D2.2 (A), R14.1
unnamed: D4.1 (K), J1.4, U1.49 (PB9/TWI1_SDA/UART0_RX/PB_EINT9), U3.6 (TXD)
unnamed: D4.2 (A), R19.2
unnamed: D5.1 (K), J1.5, U1.48 (PB8/TWI1_SCK/UART0_TX/PB_EINT8), U3.7 (RXD)
unnamed: D5.2 (A), R20.2, R28.2
unnamed: J5.5 (CLK), R22.1
unnamed: J5.1 (DAT2), R23.2, R34.1, U1.101 (PF5/SDC0_D2/JTAG_CK1)
unnamed: J5.2 (DAT3/CD), R35.1, RN1.2 (R1), U1.102 (PF4/SDC0_D3/UART0_RX)
unnamed: J5.3 (CMD), RN1.3 (R2), U1.103 (PF3/SDC0_CMD/JTAG_DO1)
unnamed: J5.7 (DAT0), RN1.4 (R3), U1.106 (PF1/SDC0_D0/JTAG_DI1)
unnamed: J5.8 (DAT1), R15.2, RN1.5 (R4), U1.107 (PF0/SDC0_D1/JTAG_MS1)
unnamed: J6.T, R25.1
unnamed: J6.R1, R24.1
unnamed: D16.1 (K), U11.36 (CHGLED)
unnamed: D16.2 (A), R45.2
unnamed: D17.2 (A), U9.1 (LX)
unnamed: FB1.1, J2.1 (VBUS)
unnamed: FB2.1, U7.9 (VDDA)
unnamed: J2.2 (D-), U3.2 (UD-)
unnamed: J2.3 (D+), U3.1 (UD+)
unnamed: J2.4 (ID), R21.1
unnamed: J3.2 (D-), U1.110 (USB-DM), U6.3 (IO2)
unnamed: J3.3 (D+), U1.111 (USB-DP), U6.1 (IO1)
unnamed: J4.1, R7.2, U1.92 (EPHY-TXP)
unnamed: J4.2, R8.2, U1.91 (EPHY-TXN)
unnamed: J4.3, R9.1, U1.90 (EPHY-RXP)
unnamed: J4.6, R10.1, U1.89 (EPHY-RXN)
unnamed: J4.10, R12.1
unnamed: J4.12, R11.1
unnamed: J7.4 (ID), R29.1
unnamed: L2.1, U8.3 (LX)
unnamed: L3.2, U11.8 (LX2)
unnamed: L4.2, U11.15 (LX3)
unnamed: L5.1, U11.45 (LX1)
unnamed: R6.1, U1.94 (EPHY-RTX)
unnamed: R16.2, U1.54 (PC2/SDC2_RST/SPI_CS), U4.1 (~CS)
unnamed: R17.2, U1.4 (PG1/SDC1_CMD/PG_EINT1), U5.M5 (CMD)
unnamed: R18.2, U5.K5 (RSTN)
unnamed: R22.2, U1.105 (PF2/SDC0_CLK/UART0_TX)
unnamed: R24.2, U1.121 (HPOUTL)
unnamed: R25.2, U1.120 (HPOUTR)
unnamed: R26.2, U1.125 (HPCOM)
unnamed: R35.2, U1.73 (SZQ)
unnamed: U9.3 (FB), U10.1 (LEDK)
unnamed: R43.2, U11.23 (BIAS)
unnamed: RN2.2 (R1), U1.3 (PG2/SDC1_D0/PG_EINT2), U5.A3 (DAT0)
unnamed: RN2.3 (R2), U1.2 (PG3/SDC1_D1/PG_EINT3), U5.A4 (DAT1)
unnamed: RN2.4 (R3), U1.1 (PG4/SDC1_D2/PG_EINT4), U5.A5 (DAT2)
unnamed: RN2.5 (R4), U1.128 (PG5/SDC1_D3/PG_EINT5), U5.B2 (DAT3)
unnamed: U1.5 (PG0/SDC1_CLK/PG_EINT0), U5.M6 (CLK)
unnamed: U1.6 (PE24/LCD_D23), U10.12 (R7)
unnamed: U1.7 (PE23/LCD_D22), U10.11 (R6)
unnamed: U1.11 (PE19/CSI_D15/LCD_D21), U10.10 (R5)
unnamed: U1.13 (PE18/CSI_D14/LCD_D20), U10.9 (R4)
unnamed: U1.14 (PE17/CSI_D13/LCD_D19), U10.8 (R3)
unnamed: U1.15 (PE16/CSI_D12/LCD_D18), U10.7 (R2)
unnamed: U1.16 (PE15/CSI_D11/LCD_D15), U10.20 (G7)
unnamed: U1.17 (PE14/CSI_D10/LCD_D14), U10.19 (G6)
unnamed: U1.18 (PE13/CSI_D9/LCD_D13), U10.18 (G5)
unnamed: U1.22 (PE12/CSI_D8/LCD_D12), U10.17 (G4)
unnamed: U1.23 (PE11/CSI_D7/LCD_D11), U10.16 (G3)
unnamed: U1.24 (PE10/CSI_D6/LCD_D10), U10.15 (G2)
unnamed: U1.27 (PE9/CSI_D5/LCD_D7), U10.28 (B7)
unnamed: U1.28 (PE8/CSI_D4/LCD_D6), U10.27 (B6)
unnamed: U1.30 (PE7/CSI_D3/LCD_D5), U10.26 (B5)
unnamed: U1.31 (PE6/CSI_D2/LCD_D4), U10.25 (B4)
unnamed: U1.32 (PE5/CSI_D1/LCD_D3), U10.24 (B3)
unnamed: U1.33 (PE4/CSI_D0/LCD_D2), U10.23 (B2)
unnamed: U1.34 (PE3/CSI_VSYNC/LCD_VSYNC), U10.33 (VSYNC)
unnamed: U1.35 (PE2/CSI_HSYNC/LCD_HSYNC), U10.32 (HSYNC)
unnamed: U1.36 (PE1/CSI_MCLK/LCD_DE), U10.34 (DEN)
unnamed: U1.37 (PE0/CSI_PCLK-/LCD_CLK), U10.30 (DCLK)
unnamed: U1.52 (PC0/SDC2_CLK/SPI_MISO), U4.2 (DO(IO1))
unnamed: U1.53 (PC1/SDC2_CMD/SPI_CLK), U4.6 (CLK)
unnamed: U1.55 (PC3/SDC2_D0/SPI_MOSI), U4.5 (DI(IO0))
unnamed: R46.2, U4.3 (IO2), U4.7 (IO3)
OSC32_IN: C89.1, U7.3 (PC14), Y3.2
OSC32_OUT: C90.1, U7.4 (PC15), Y3.1
OSC_IN: C87.1, U7.5 (PF0), Y4.1
PWM0: U1.43 (PB4/PWM0/PB_EINT4), U9.4 (EN/PWM)
Pwron: C77.2, R42.2, U11.47 (PWRON)
SPD__LED: R11.2, R13.2, U1.78 (EPHY-SPD-LED)
USART1_RX: U1.9 (PE21/CSI_SCK/TWI1_SCK/UART1_TX), U7.13 (PA3)
USART1_TX: U1.8 (PE22/CSI_SDA/TWI1_SDA/UART1_RX), U7.12 (PA2)
VCC: C52.1, C73.1, C74.1, C75.1, C76.1, C82.1, C83.1, J3.1 (VBUS), R28.1, R40.1, R45.1, U6.5 (VP), U8.4 (VIN), U9.6 (VDD), U11.7 (VIN2), U11.14 (VIN3), U11.21 (APS), U11.29 (DC3SET), U11.34 (IPSOUT@1), U11.35 (IPSOUT@2), U11.44 (VIN1)
VDD: C34.1, C57.2, R44.2, U1.98 (VCC-RTC), U11.28 (LDO1)
reset: R44.1, U1.99 (RESET), U11.25 (PWROK)
scl: U1.45 (PB6/TWI0_SCK/PB_EINT6), U11.2 (SCK)
sda: U1.46 (PB7/TWI0_SDA/PB_EINT7), U11.1 (SDA)

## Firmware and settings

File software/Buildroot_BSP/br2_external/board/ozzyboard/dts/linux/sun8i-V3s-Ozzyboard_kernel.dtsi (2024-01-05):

#include <dt-bindings/interrupt-controller/arm-gic.h>
//#include <dt-bindings/clock/sun6i-rtc.h>
#include <dt-bindings/clock/sun8i-v3s-ccu.h>
#include <dt-bindings/reset/sun8i-v3s-ccu.h>
#include <dt-bindings/clock/sun8i-de2.h>

/ {
	#address-cells = <1>;
	#size-cells = <1>;
	interrupt-parent = <&gic>;

	chosen {
		#address-cells = <1>;
		#size-cells = <1>;
		ranges;

		framebuffer-lcd {
			compatible = "allwinner,simple-framebuffer",
				     "simple-panel";
			allwinner,pipeline = "mixer0-lcd0";
			clocks = <&display_clocks CLK_MIXER0>,
				 <&ccu CLK_TCON0>;
			status = "disabled";
		};
	};

	cpus {
		#address-cells = <1>;
		#size-cells = <0>;

		cpu@0 {
			compatible = "arm,cortex-a7";
			device_type = "cpu";
			reg = <0>;
			clocks = <&ccu CLK_CPU>;
		};
	};
	
	de: display-engine {
		compatible = "allwinner,sun8i-v3s-display-engine";
		allwinner,pipelines = <&mixer0>;
		status = "disabled";
	};
	

	timer {
		compatible = "arm,armv7-timer";
		interrupts = <GIC_PPI 13 (GIC_CPU_MASK_SIMPLE(4) | IRQ_TYPE_LEVEL_LOW)>,
			     <GIC_PPI 14 (GIC_CPU_MASK_SIMPLE(4) | IRQ_TYPE_LEVEL_LOW)>,
			     <GIC_PPI 11 (GIC_CPU_MASK_SIMPLE(4) | IRQ_TYPE_LEVEL_LOW)>,
			     <GIC_PPI 10 (GIC_CPU_MASK_SIMPLE(4) | IRQ_TYPE_LEVEL_LOW)>;
	};

	clocks {
		#address-cells = <1>;
		#size-cells = <1>;
		ranges;

		osc24M: osc24M_clk {
			#clock-cells = <0>;
			compatible = "fixed-clock";
			clock-frequency = <24000000>;
			clock-accuracy = <50000>;
			clock-output-names = "osc24M";
		};

		osc32k: osc32k_clk {
			#clock-cells = <0>;
			compatible = "fixed-clock";
			clock-frequency = <32768>;
			clock-accuracy = <50000>;
			clock-output-names = "ext-osc32k";
		};
	};

	soc {
		compatible = "simple-bus";
		#address-cells = <1>;
		#size-cells = <1>;
		ranges;	
		
		display_clocks: clock@1000000 {
			compatible = "allwinner,sun8i-v3s-de2-clk";
			reg = <0x01000000 0x10000>;
			clocks = <&ccu CLK_BUS_DE>,
				 <&ccu CLK_DE>;
			clock-names = "bus",
				      "mod";
			resets = <&ccu RST_BUS_DE>;
			#clock-cells = <1>;
			#reset-cells = <1>;
		};	
		
		mixer0: mixer@1100000 {
			compatible = "allwinner,sun8i-v3s-de2-mixer";
			reg = <0x01100000 0x100000>;
			clocks = <&display_clocks 0>,
				 <&display_clocks 6>;
			clock-names = "bus",
				      "mod";
			resets = <&display_clocks 0>;

			ports {
				#address-cells = <1>;
				#size-cells = <0>;

				mixer0_out: port@1 {
					reg = <1>;

					mixer0_out_tcon0: endpoint {
						remote-endpoint = <&tcon0_in_mixer0>;
					};
				};
			};
		};
		
		syscon: system-control@1c00000 {
			compatible = "allwinner,sun8i-v3s-system-control",
				     "allwinner,sun8i-h3-system-control";
			reg = <0x01c00000 0xd0>;
			#address-cells = <1>;
			#size-cells = <1>;
			ranges;
		};
		
		nmi_intc: interrupt-controller@1c000d0 {
			compatible = "allwinner,sun8i-v3s-nmi",
				     "allwinner,sun9i-a80-nmi";
			interrupt-controller;
			#interrupt-cells = <2>;
			reg = <0x01c000d0 0x0c>;
			interrupts = <GIC_SPI 32 IRQ_TYPE_LEVEL_HIGH>;
		};

		dma: dma-controller@1c02000 {
			compatible = "allwinner,sun8i-v3s-dma";
			reg = <0x01c02000 0x1000>;
			interrupts = <GIC_SPI 50 IRQ_TYPE_LEVEL_HIGH>;
			clocks = <&ccu CLK_BUS_DMA>;
			resets = <&ccu RST_BUS_DMA>;
			#dma-cells = <1>;
		};
		
		tcon0: lcd-controller@1c0c000 {
			compatible = "allwinner,sun8i-v3s-tcon";
			reg = <0x01c0c000 0x1000>;
			interrupts = <GIC_SPI 86 IRQ_TYPE_LEVEL_HIGH>;
			clocks = <&ccu CLK_BUS_TCON0>,
				 <&ccu CLK_TCON0>;
			clock-names = "ahb",
				      "tcon-ch0";
			clock-output-names = "tcon-data-clock";
			#clock-cells = <0>;
			resets = <&ccu RST_BUS_TCON0>;
			reset-names = "lcd";
			status = "disabled";

			ports {
				#address-cells = <1>;
				#size-cells = <0>;

				tcon0_in: port@0 {
					reg = <0>;

					tcon0_in_mixer0: endpoint {
						remote-endpoint = <&mixer0_out_tcon0>;
					};
				};

				tcon0_out: port@1 {
					#address-cells = <1>;
					#size-cells = <0>;
					reg = <1>;
				};
			};
		};

		


		mmc0: mmc@1c0f000 {
			compatible = "allwinner,sun7i-a20-mmc";
			reg = <0x01c0f000 0x1000>;
			clocks = <&ccu CLK_BUS_MMC0>,
				 <&ccu CLK_MMC0>,
				 <&ccu CLK_MMC0_OUTPUT>,
				 <&ccu CLK_MMC0_SAMPLE>;
			clock-names = "ahb",
				      "mmc",
				      "output",
				      "sample";
			resets = <&ccu RST_BUS_MMC0>;
			reset-names = "ahb";
			interrupts = <GIC_SPI 60 IRQ_TYPE_LEVEL_HIGH>;
			pinctrl-names = "default";
			pinctrl-0 = <&mmc0_pins>;
			status = "disabled";
			#address-cells = <1>;
			#size-cells = <0>;
		};

		mmc1: mmc@1c10000 {
			compatible = "allwinner,sun7i-a20-mmc";
			reg = <0x01c10000 0x1000>;
			clocks = <&ccu CLK_BUS_MMC1>,
				 <&ccu CLK_MMC1>,
				 <&ccu CLK_MMC1_OUTPUT>,
				 <&ccu CLK_MMC1_SAMPLE>;
			clock-names = "ahb",
				      "mmc",
				      "output",
				      "sample";
			resets = <&ccu RST_BUS_MMC1>;
			reset-names = "ahb";
			interrupts = <GIC_SPI 61 IRQ_TYPE_LEVEL_HIGH>;
			pinctrl-names = "default";
			pinctrl-0 = <&mmc1_pins>;
			status = "disabled";
			#address-cells = <1>;
			#size-cells = <0>;
		};

		mmc2: mmc@1c11000 {
			compatible = "allwinner,sun7i-a20-mmc";
			reg = <0x01c11000 0x1000>;
			clocks = <&ccu CLK_BUS_MMC2>,
				 <&ccu CLK_MMC2>,
				 <&ccu CLK_MMC2_OUTPUT>,
				 <&ccu CLK_MMC2_SAMPLE>;
			clock-names = "ahb",
				      "mmc",
				      "output",
				      "sample";
			resets = <&ccu RST_BUS_MMC2>;
			reset-names = "ahb";
			interrupts = <GIC_SPI 62 IRQ_TYPE_LEVEL_HIGH>;
			status = "disabled";
			#address-cells = <1>;
			#size-cells = <0>;
		};

		crypto@1c15000 {
			compatible = "allwinner,sun8i-v3s-crypto",
				     "allwinner,sun8i-a33-crypto";
			reg = <0x01c15000 0x1000>;
			interrupts = <GIC_SPI 80 IRQ_TYPE_LEVEL_HIGH>;
			clocks = <&ccu CLK_BUS_CE>, <&ccu CLK_CE>;
			clock-names = "ahb", "mod";
			dmas = <&dma 16>, <&dma 16>;
			dma-names = "rx", "tx";
			resets = <&ccu RST_BUS_CE>;
			reset-names = "ahb";
		};

		usb_otg: usb@1c19000 {
			compatible = "allwinner,sun8i-h3-musb";
			reg = <0x01c19000 0x0400>;
			clocks = <&ccu CLK_BUS_OTG>;
			resets = <&ccu RST_BUS_OTG>;
			interrupts = <GIC_SPI 71 IRQ_TYPE_LEVEL_HIGH>;
			interrupt-names = "mc";
			phys = <&usbphy 0>;
			phy-names = "usb";
			extcon = <&usbphy 0>;
			status = "disabled";
		};

		usbphy: phy@1c19400 {
			compatible = "allwinner,sun8i-v3s-usb-phy";
			reg = <0x01c19400 0x2c>,
			      <0x01c1a800 0x4>;
			reg-names = "phy_ctrl",
				    "pmu0";
			clocks = <&ccu CLK_USB_PHY0>;
			clock-names = "usb0_phy";
			resets = <&ccu RST_USB_PHY0>;
			reset-names = "usb0_reset";
			status = "disabled";
			#phy-cells = <1>;
		};

		ccu: clock@1c20000 {
			compatible = "allwinner,sun8i-v3s-ccu";
			reg = <0x01c20000 0x400>;
			//clocks = <&osc24M>, <&rtc CLK_OSC32K>;
			clocks = <&osc24M>, <&rtc 0>;
			clock-names = "hosc", "losc";
			#clock-cells = <1>;
			#reset-cells = <1>;
		};
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

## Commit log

2023-03-07 cleaning and naming
    [Audio_Video.kicad_sch, Clocks_Buttons.kicad_sch, Connections.kicad_sch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]
2023-03-07 removed old schematics
    [untitled.kicad_sch, untitled2.kicad_sch, untitled3.kicad_sch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]
2023-03-25 PCB done
    [Audio_Video.kicad_sch, Clocks_Buttons.kicad_sch, Connections.kicad_sch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]
2023-03-25 added data, picture and BOM
    [lb_mp1.csv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]
2023-07-22 update schematic pdf
2023-07-31 Adding BSP environment
    Added BSP generation with buildroot and BR2_EXTERNAL
    Device tree modified for LCD and AXP209
    Added Pull-up to I2C
    Added default ETH config
    [Audio_Video.kicad_sch, Clocks_Buttons.kicad_sch, Connections.kicad_sch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]
2023-10-19 kernel 5.3, added packages and LCD drivers
    [genimageSD.cfg]
2023-10-21 Added support for SPI, flashrom utility, and tweak to boot from SPI NOR
    [genimage-eMMC.cfg]
2024-01-05 Change in folder structure and RevB added
    Changes include :
    - Changed the Ethernet port orientation
    - Changed power supply of Serial to USB chip for the board own power, no accidental pull down now.
    - USB ports are more on board.
    - Activity led added with PF6
    - Battery pins are JST compatible
    - Added input for +5V
    - UART serial port is now near serial USB
    - Added func button for STM32
    - Added pull up resistor for i2c0
    - Added Shift register with 2 x 4 leds for CPU and memory usage
    - Added EEPROM 2kbits
    - fixed issue with pull-up resistor for eMMC (worked without it anyway)
2024-01-05 added all files for RevB
    [Audio_Video.kicad_sch, Clocks_Buttons.kicad_sch, Connections.kicad_sch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]
2024-01-18 Removed gerber files, reajusted paths for files, added photo and PDF
    [Audio_Video.kicad_sch, Clocks_Buttons.kicad_sch, Connections.kicad_sch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]
